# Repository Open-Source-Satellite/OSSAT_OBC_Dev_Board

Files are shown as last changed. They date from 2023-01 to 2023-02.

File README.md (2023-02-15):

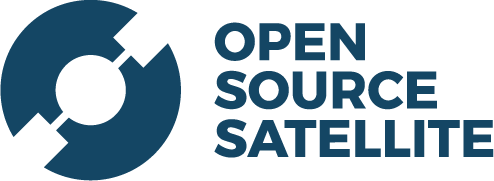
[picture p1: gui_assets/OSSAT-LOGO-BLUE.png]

# Open Source Satellite Development On Board Computer

## Contents
- [Background](#background)
- [Introduction to the OBC Development Board](#Introduction-to-the-OBC-Development-Board)
- [OBC Development Board Manual](#OBC-Development-Board-Manual)
- [Running the OSSAT OBC Application](#running-the-ossat-obc-application)

## Background
The key drivers for the Open Source Satellite (OSSAT) are to improve the affordability, accessibility and
sustainability of space; to address the market need for an improvement in the
price:performance point of small satellites; to stimulate the next wave of disruption
in the small satellite industry; and to enable the development of new missions,
applications and services.
<p style="text-align: center;">
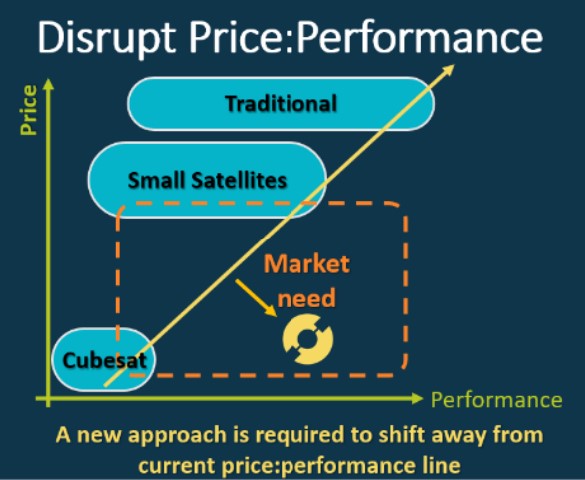
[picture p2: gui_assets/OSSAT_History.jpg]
OSSAT History

</p>
Small satellites initiated the initial market
disruption by leveraging COTS parts and
processes, but it appears that the unit cost
per spacecraft cannot be reduced much
further.  
CubeSats have been critical in recent years for
lowering the barriers to entry, however they
appear to be unable to provide sufficient
robustness and mission enabling capability to
support more demanding missions.  
The goal is to develop OSSAT to fill this gap and deliver microsatellite-class
performance for a CubeSat price, even when manufacturing in low volumes. The
aim is to increase the level of integration and robustness over subsequent missions
in order to develop a single platform that is affordable for use in vLEO (very Low
Earth Orbit), LEO (Low Earth Orbit), GEO (Geosynchronous Equatorial Orbit), Lunar and
interplanetary missions.  
OSSAT will be a performant and flexible
system that KISPE Space will be able to use to implement some of its own
commercial missions; however, simply using it for KISPE Space missions will not
result in the desired increase in accessibility to the design, nor stimulate the
market.  
Making the OSSAT design open source will maximise access and achieve the wider aims of the
Programme.  

## Introduction to the OBC Development Board
### Overview
The OSSAT OBC Development board provides a convenient hardware platform that collaborators can use, to develop satellite firmware.
The board is based upon the STM32 microcontroller and includes various interfaces for connection to other satellite sub-systems. 
The board includes an STLink programmer/debugger interface to facilitate firmware development and debugging activities.
The design shares several attributes with a sister board that is being developed for a space application.
Figure 1 shows a view of the board.

   
Figure 1:  View of the Board
<br/>
<br/>
### Features
- STM32 Microcontroller (STM32H753ZIT)
- SRAM 4Mx16bit (8Mx8bit) CMOS Static RAM
- STLink Programming and Debug interface (with UART)
- 2x CAN Bus channels (with local 120R termination), with D-Sub (9 way sockets)
- 2x UART interface
- 8x Thermistor interface (10K Negative Temperature Coefficient)
- 31x General purpose I/O lines
- Local 3V3 regulator, operating from USB supply, via Micro-USB connector
- MCU Reset Button
- 2x push-buttons for test use
- 3x status LEDs for test use
- 2x power status LEDs
- Real-time clock

### Technical Details
#### Board Overview
Figure 2 below shows a view of the fully assembled board. There are no components on the reverse side.

   
Figure 2:  View of Assembled Board
<br/>   
<br/> 
The block diagram for the Schematic is shown in Figure 3.

   
Figure 3:  Schematic Block Diagram
<br/>   
<br/> 
#### STM32 Microcontroller (STM32H753ZIT)
The STM32 MCU includes a broad set of internal features, some of which are highlighted below:
- 32-bit Arm®-M7 core
- 2Mbyte onboard Flash
- 1Mbyte RAM
- Flexible Memory controller
- Power management
- Watchdog
- Multiple communication peripherals, including CAN, I2C, SPI, UART
- ADC
- Timers and RTC
- Large number of I/O ports
- STLink / JTAG compatibility

Full details of the MCU are available from the manufacturers data sheet and reference manual, available from the STM web site. Refer to:
- DS12117: STM32H753xl Datasheet (32-bit Arm® Cortex®-M7 480MHz MCUs, 2MB Flash, 1MB RAM, 46 com. and analogue interfaces, crypto)
- RM0433: Reference manual, STM32H742, STM32H743/753 and STM32H750 Value line advanced Arm®-based 32-bit MCUs

### Related Documents
A list of documents related to this board is provided in the Manual and is listed here. This includes diagrams, design source files, manufacturing and & test information and test firmware.
- [KS-SCH-01466 (.PDF)](https://github.com/Open-Source-Satellite/OSSAT_OBC_Dev_Board/blob/main/OSSAT%20OBC%20Dev%20Board%20Drawings/KS-SCH-01466-01%20OSSAT%20OBC%20Dev%20Board%20Schematic.p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) OSSAT OBC Development Board Schematic (Schematic diagram)
- [KS-SCH-01466 (.sch)](https://github.com/Open-Source-Satellite/OSSAT_OBC_Dev_Board/blob/main/OSSAT%20OBC%20Dev%20Board%20Drawings/CAD%20Source%20Files/KS-SCH-01466-01%20OSSAT%20OBC%20Dev%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) OSSAT OBC Development Board Schematic (Fusion 360 schematic source file, in ‘Eagle’ format)
- [KS-SCH-01466 (.lbr)](https://github.com/Open-Source-Satellite/OSSAT_OBC_Dev_Board/blob/main/OSSAT%20OBC%20Dev%20Board%20Drawings/CAD%20Source%20Files/KS-SCH-01466-01%20OSSAT_OBC_Dev_Boar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) OSSAT OBC Dev board library (Fusion 360 Library file in ‘Eagle’ format, for parts used in the design)
- [KS-SCH-01466 (.xlsx)](https://github.com/Open-Source-Satellite/OSSAT_OBC_Dev_Board/blob/main/OSSAT%20OBC%20Dev%20Board%20Drawings/KS-SCH-01466-01%20OSSAT%20OBC%20Dev%20Brd%20BOM%20with%20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) OSSAT OBC Dev Board BOM with manufacturer data (Bill of materials for the board assembly)
- [KS-BRD-01467 (.brd)](https://github.com/Open-Source-Satellite/OSSAT_OBC_Dev_Board/blob/main/OSSAT%20OBC%20Dev%20Board%20Drawings/CAD%20Source%20Files/KS-SCH-01467%20OSSAT%20OBC%20Dev%20B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) OSSAT OBC Development Board PCB (Fusion 360 PCB source file in ‘Eagle’ format)
- [KS-BRD-01467 (.zip)](https://github.com/Open-Source-Satellite/OSSAT_OBC_Dev_Board/blob/main/OSSAT%20OBC%20Dev%20Board%20Drawings/Gerber%20Files/KS-BRD-01467-02%20OSSAT%20Sw%20Dev%20Board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) OSSAT OBC Dev Board PCB Manufacturing files	(Gerber file set and PnP file)
- [KS-BRD-01467 (.docx)](https://github.com/Open-Source-Satellite/OSSAT_OBC_Dev_Board/blob/main/OSSAT%20OBC%20Dev%20Board%20Drawings/KS-BRD-01467-02%20OSSAT%20OBC%20Dev%20board%20PCB%20Layer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) OSSAT OBC Dev Board Layer Stack-up (Defines the layer stack and pcb materials / thicknesses for the board)
- [KS-DOC-01526 (.docx)](https://github.com/Open-Source-Satellite/OSSAT_OBC_Dev_Board/blob/main/OSSAT%20OBC%20Dev%20Board%20Drawings/KS-DOC-01526-02%20OSSAT%20OBC%20Dev%20Board%20Verificatio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) OSSAT OBC Dev Board Verification Procedure	(Used to confirm board function after build)
- [KS-DOC-01529 (.docx)](https://github.com/Open-Source-Satellite/OSSAT_OBC_Dev_Board/blob/main/OSSAT%20OBC%20Dev%20Board%20Drawings/KS-DOC-01529-01%20OSSAT%20OBC%20Dev%20Board%20Build%20Doc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) OSSAT OBC Dev Board Build Document (Build process control document)
- [KS-SOF-01541 (software)](https://github.com/Open-Source-Satellite/OSSAT_OBC_Dev_Board/releases/tag/KS-SOF-01541-01) Software to support h/w test of the OSSAT OBC dev board	(Test Software)

## OBC Development Board Manual
Document [KS-DOC-01543 is the manual](https://github.com/Open-Source-Satellite/OSSAT_OBC_Dev_Board/blob/main/KS-DOC%2001543-01%20OSSAT%20OBC%20Dev%20Board%20Manual.docx) for the board. It covers:
- Board features
- Technical details
- Building the board
- Testing the board
- Using the board

## Running the OSSAT OBC Application
Within one year of the first launch of the OSSAT, the OSSAT OBC Application software will become open source. In the interim time, in order to develop/build and run the OSSAT OBC Application, you'll need to become an OSSAT collaborator ([Click Here](https://www.opensourcesatellite.org/register/)).
If you are an OSSAT collaborator, that's great... Click [here](/OBC_CODE_README.md) to find out how to run the OSSAT OBC Application on this development board.

## Licenses
All information in this repository is licensed Open Source through the Creative Commons license:

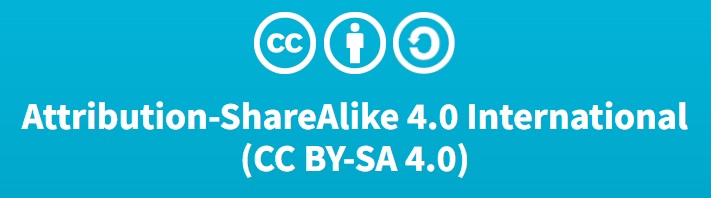
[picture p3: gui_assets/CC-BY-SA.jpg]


## Get Involved
If you wish to contribute directly to the development of OSSAT, have a look at the existing Github issues and register [here](https://www.opensourcesatellite.org/register/).

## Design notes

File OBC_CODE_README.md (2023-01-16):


# Running application code on the OBC
This readme gives the details you'll need to run our OSSAT application on our OSSAT OBC development board, it also gives details of how to use the simple command line interface and how to get the file system going.  

## Contents
- [Building the code](#building-the-code)
- [Running the code](#running-the-code)
- [Using the CLI](#using-the-cli)
- [Formatting the disk](#formatting-the-disk)
- [Downloading files](#deownloading-files)
- [Uploading files](#uploading-files)
- [Reading the Command and Error Log](#reading-the-command-and-error-log)

## Building the code
If you are an OSSAT collaborator, you'll be able to access the OBC application code at [this](https://github.com/Open-Source-Satellite/OSS-Demo-Project-STM32H7) repository. For information about building the code, go to this repository.

**NOTE: The STMCubeIDE project includes build configurations for different builds (e.g. Unit Tests, Bootloader, Main Application etc). Therefore, before hitting the build button, you'll need to switch to the relevant build configuration which is MAIN_IMAGE_DEBUG_SECTOR_0_KS_OBC. This change can be made by navigating to the Project dropdown->Build Configurations->Set Active->MAIN_IMAGE_DEBUG_SECTOR_0_KS_OBC. See the below image:**

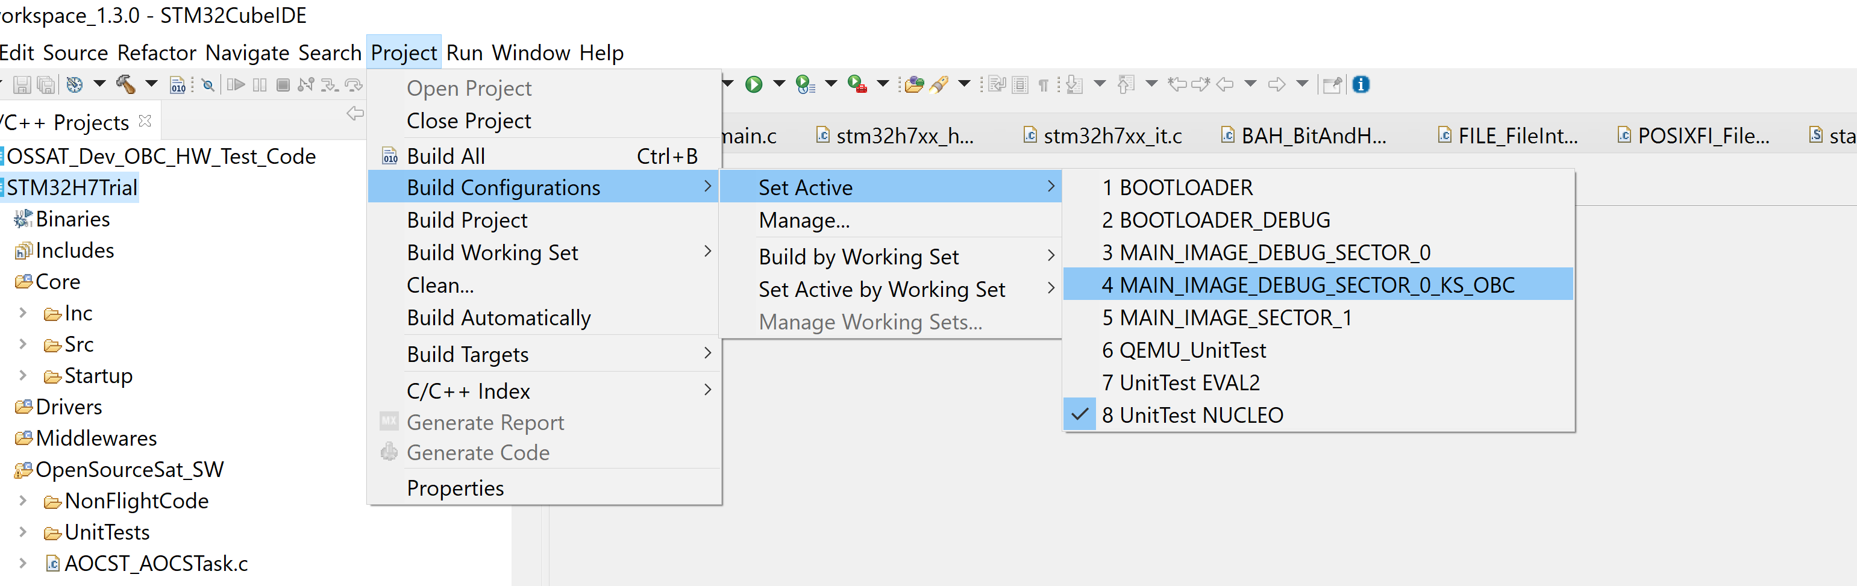
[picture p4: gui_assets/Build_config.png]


## Running the code
In order to run the code, you'll need some form of UART/Serial terminal program. We tend to use [TeraTerm](https://ttssh2.osdn.jp/index.html.en). You'll also need an [ST Link SWD/JTAG device](https://www.st.com/en/development-tools/stlink-v3set.html). The board is designed with a compatible SWD/JTAG connector.

Perform the following procedure:
1. Connect the ST Link to the board at one end and to your PC running STM Cube on the other end.



2. Apply 5V to the micro USB power connection to the board (a seperate connector to the ST-Link). (setting any relevant current limit to 0.5A should provide plenty of power to overcome in-rush).
3. Run your chosen terminal program at 115200 baud 8-N-1 configuration. Select the COM port labelled "STMicroelectronics STLink Virtual COM Port"

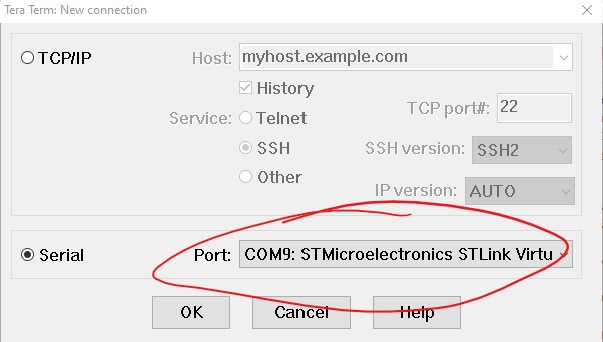
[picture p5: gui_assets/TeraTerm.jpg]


4. Once the code is built, you can either load and run (the green "go" icon) OR load, and debug run (the bug symbol) 



5. You should now observe some output on the Command Line Interface (CLI) through your chosen serial program.

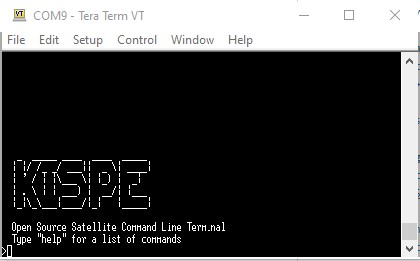
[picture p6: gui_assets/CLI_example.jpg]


6. Typing "help" into the CLI will list the available commands.

## Formatting the disk
Since the OSSAT development board does not include non-volatile memory (unlike the flight version that makes use of MRAM), you'll need to format the disk following any power cycle. The board features 8 MBytes of SRAM that can be formatted using the CLI command "fdisk OSS:/"
You may notice some error messages in response to the disk formatting that relate to the closure of files that may not exist.

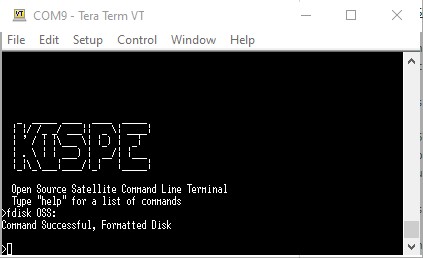
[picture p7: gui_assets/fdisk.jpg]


Once formatted... Another reset (via the MCU reset button) will cause the command and error log file to be created.

## Downloading files
You'll find that you can navigate around the file system through the Linux-esque commands such as "ls", "cd", "pwd". You can also use the download command to download files, the command gives you 10 seconds (to start file logging in your chosen serial program) before printing the content of the file to the serial terminal.

## Uploading files
At the time of writing, the CLI code uses inefficient STDIO function calls to read the serial data. These calls are too slow to keep up with serial data at the maximum rate. Therefore, we've written a small Windows Powershell utility that slows down the data transmission to a level that the STDIO calls can support. Therefore, in order to upload files, run the following steps:

1. Install PowerShell v7+ for Windows.
2. navigate to the "Scripts" subdirectory in the STM32Cube Project.
3. Disconnect any serial programs from the serial port
4. run the "file_uploader.ps1" script
```bash
./file_uploader 
```

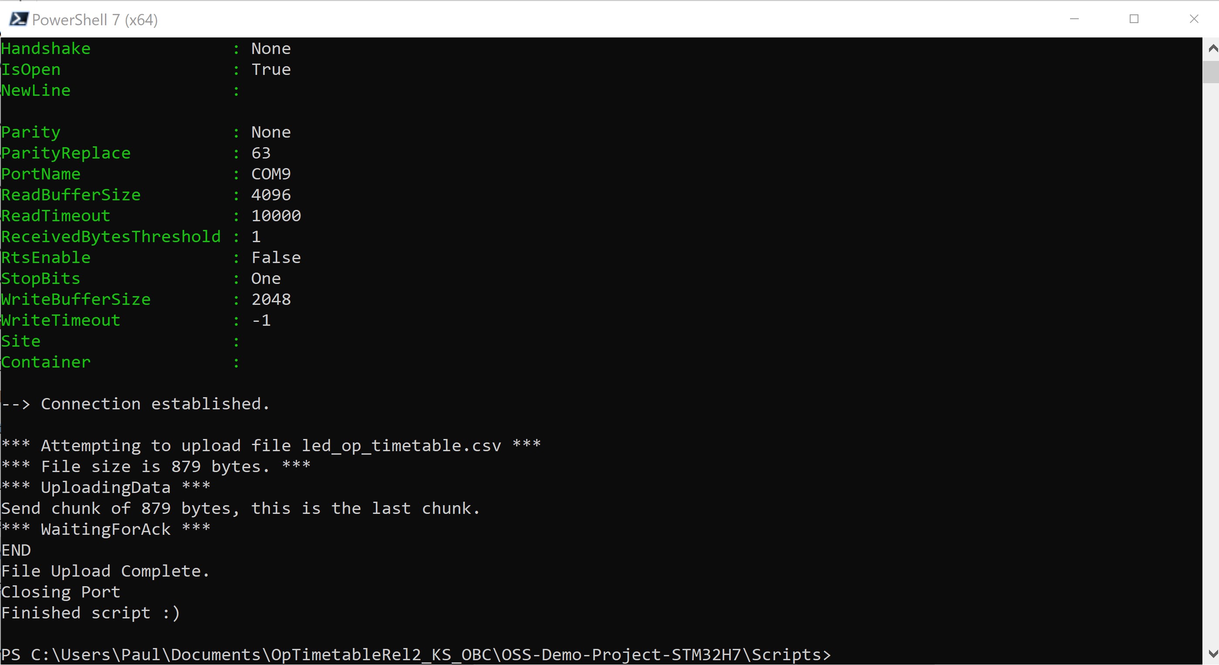
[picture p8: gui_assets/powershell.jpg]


**NOTE: there are other powershell command line options available that can e.g. change baud rate, change destination path/name etc etc. Open the script to observe the full list.**

## Reading the Command and Error Log
The OBC software includes a command and error log that records lot of the activities performed on board. To see this history, naviagate to the OSS:/CmdAndErrLogs directory and download the latest file.

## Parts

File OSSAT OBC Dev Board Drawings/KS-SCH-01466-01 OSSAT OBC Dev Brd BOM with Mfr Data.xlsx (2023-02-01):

KS-SCH-01466-01 OSSAT OBC Dev Board Bill of Materials
To be used with shematic KS-SCH-01466-01 Schematic and KS-SCH-01466-02 PCB artwork
Item no | Qty | Refs | Description | Manufacturer | Manf Part number | Vendor | Stock No
1 | 1 | C58 | 100pF MLCC 0805 COG 50V 5% | Kemet | C0805C101J5GACTU | Farnell | 1414656
2 | 2 | C35, C36 | 10pF MLCC 0805 COG 50V 5% Q200 | Kemet | C0805C100J5GACAUTO | Farnell | 2070433
3 | 0 | C16, C17 | #N/A | #N/A | #N/A | #N/A | #N/A
4 | 24 | C1, C6, C7, C8, C9, C10, C11, C12, C13, C14, C15, C18, C19, C20, C25, C26, C28, C31, C34, C37, C38, C39, C48, C63 | 100nF MLCC 0805 X7R 50V 10% | Kemet | C0805C104K5RACTU | Farnell | 1414664
5 | 2 | C24, C49 | 47nF MLCC 0805 X7R 50V 10% Q200 | Kemet | C0805C473K5RACAUTO | Farnell | 2070486
6 | 12 | C27, C29, C30, C32, C40, C41, C42, C43, C44, C45, C46, C47 | 1uF MLCC 0805 X7R 25V 10% | Kemet | C0805C105K3RECTU | Farnell | 2991344
7 | 1 | C5 | 4u7 MLCC 0805 X7R 16V 10% | Kemet | C0805C475K4RACTU | Farnell | 2118133
8 | 2 | C3, C4 | 2u2 MLCC 0805 X7R 16V 10% Q200 | Kemet | C0805C225K4RECAUTO | Farnell | 2991362
9 | 1 | C64 | 10uF MLCC 1210 X7R 25V 10% Q200 | Kemet | C1210C106K3RACAUTO | Farnell | 2070524
10 | 4 | C2, C21, C22, C23 | 47uF MLCC 1210 X7R 10V 10% | Murata | GRM32ER71A476KE15L | Farnell | 1797018
11 | 1 | C57 | 470uF ELECTROLYTIC 16V 20% PTH 10Dx12.5Hx5P Rubycon YXF | Rubycon | 16YXF470MEFC10X12.5 | Farnell | 1144616
12 | 2 | J3, J4 | 52F 2 Row Skt-Strip 2.54P Samtec ESQ-nnn-12-G-D | Samtec | ESQ-126-12-G-D | Farnell | 2856394
13 | 1 | J1 | 14M 2 Row Micro Header 1.27p Samtec FTSH-1nn-01-F-D-K | Samtec | FTSH-107-01-F-D-K | Mouser | 200-FTSH10701FDK
14 | 2 | J7, J8 | 9F D-Sub Vert Scw-Post Amphenol FCI DELTA-D | Amphenol FCI | LD09S24A4GV00LF | Farnell | 3367583
15 | 1 | J6 | Micro-USB 90deg Amphenol 10103594-0001LF | Amphenol | 10103594-0001LF | Farnell | 2293752
16 | 0 | TP1, TP2, TP3, TP4, TP5, TP6, TP7, TP8, TP9, TP10, TP11, TP12, TP13, TP14, TP15, TP16, TP17 | #N/A | #N/A | #N/A | #N/A | #N/A
17 | 5 | D2, D3, D9, D10, D11 | BAT54S Dual Schottky SOT23 diodes in series | NXP | BAT54S,215 | Farnell | 1081194
18 | 1 | U4 | 74LVC138AD 3-8 decoder SOIC16 Max 125C | NXP | 74LVC138AD,118 | Farnell | 2463808
19 | 2 | U12, U15 | IS61WV204816BLL-10TLI SRAM 4MByte (2Mx16) 48pin-TSOP Max 85C | ISSI | IS61WV204816BLL-10TLI | Mouser | 870-WV204816BLL10TLI
20 | 1 | U2 | STM32H753ZIT6 MCU 144pin Max 85C | STM | STM32H753ZIT6 | Farnell | 2851002
21 | 1 | U13 | 3V3 LFnnABV LDO Regulator TO-220 Max 125C | STM | LF33ABV | Farnell | 1087184
22 | 2 | U10, U11 | MAX33054EASA+ CAN-Tranceiver SOIC8 Max 125C | Maxim | MAX33054EASA+ | Farnell | 2915380
23 | 2 | FB1, FB2 | 600R Bead 0805 600R at 100MHz WE-CBF-SMD | Wurth | 742792040 (WE-CBF-SMD) | Farnell | 1635735
24 | 0 | H1, H2, H3, H4, H5, H6 | #N/A | #N/A | #N/A | #N/A | #N/A
25 | 5 | LED1, LED2, LED3, LED4, LED5 | LED Yellow 0805 120deg 590nm 150mcd | Kingbright | APT2012SYCK | Mouser | 604-APT2012SYCK
26 | 1 | X1 | Xtal 32.768KHz 12p5 Max 125c Size 3.2x1.5x0.8 | NDK | NX3215SA-32.768K-STD-MUS-2 | Mouser | 344-NX3215SA32768K2
27 | 1 | X2 | Xtal 25MHz 10pF Max 125c Size 2.0x1.6x0.45 | Abracon | ABM11AIG-25.000MHZ-4Z-T3 | Farnell | 3819707
28 | 5 | R4, R8, R9, R25, R28 | 0R RES 0805 LINK 2A | NIC COMPONENTS | NRC10ZOTRF | Farnell | 3223535
29 | 5 | R15, R16, R19, R20, R37 | 100R RES 0805 0.125W 1% AEC-Q200 | Vishay | CRCW0805100RFKEA | Farnell | 1469862
30 | 3 | R83, R84, R85 | 10K RES 0805 0.125W 1% AEC-Q200 | Vishay | CRCW080510K0FHEAP | Farnell | 3546411
31 | 1 | R86 | 1K RES 0805 0.125W 1% AEC-Q200 | Vishay | CRCW08051K00FKEA | Mouser | 71-CRCW0805-1.0K-E3
32 | 1 | R43 | 200R RES 0805 0.125W 1% AEC-Q200 | Vishay | CRCW0805200RFKEA | Farnell | 1469895
33 | 1 | R38 | 2K RES 0805 0.125W 1% AEC-Q200 | Vishay | CRCW08052K00FKEA | Mouser | 71-CRCW0805-2.0K-E3
34 | 4 | R65, R78, R81, R89 | 33R RES 0805 0.125W 1% AEC-Q200 | Panasonic | ERJP06F33R0V | Farnell | 1750735
35 | 7 | R13, R17, R35, R36, R63, R79, R82 | 47K RES 0805 0.125W 1% AEC-Q200 | Vishay | CRCW080547K0FKEB | Farnell | 3546437
36 | 3 | R5, R6, R14 | 4K7 RES 0805 0.125W 1% AEC-Q200 | Vishay | CRCW08054K70FKEA | Farnell | 1469923
37 | 4 | R26, R27, R29, R30 | 60R4 RES 0805 0.125W 1% AEC-Q200 | Panasonic | ERJ6ENF60R4V | Farnell | 2303416
38 | 1 | R87 | 68R RES 0805 0.125W 1% AEC-Q200 | Vishay | RCS080568R0FKEA | Farnell | 3235183
39 | 4 | R21, R22, R23, R24 | 910R RES 0805 0.125W 1% AEC-Q200 | Vishay | CRCW0805910RFKEA | Mouser | 71-CRCW0805910RFKEA
40 | 0 | R39, R40, R41, R42, R44, R45, R46, R88 | #N/A | #N/A | #N/A | #N/A | #N/A
41 | 4 | R1, R2, R11, R12 | 10K RES 4-isolated 1206 1% Q200 | Bourns | CAY16A-1001F4LF | Farnell | 3754800
42 | 2 | R3, R10 | 1K RES 4-isolated 1206 1% Q200 | Bourns | CAY16A-1001F4LF | Farnell | 3754799
43 | 3 | S1, S2, S3 | 1PST SMD Momentary push-button 12V 50mA | Sparkfun | COM-08720 | Mouser | 474-COM-08720
44 | 1 | D4 | 3V3 TVS CDSOD323-Tnn 350W Unidirectional | Bourns | CDSOD323-T03 | Farnell | 2341910
45 | 1 | D1 | 5V0 TVS CDSOD323-Tnn 350W Unidirectional | Bourns | CDSOD323-T05 | Farnell | 2341914

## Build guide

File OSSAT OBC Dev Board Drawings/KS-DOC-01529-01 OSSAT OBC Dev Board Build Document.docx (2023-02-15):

KS-BRD01529-01: OSSAT OBC Dev board build document

This document defines the prototype build process for this PCB assembly. It covers the process from: purchasing, through assembly and test. The reference for this document is in the footer.

General Informaiton

General
This document (reference) | KS-DOC-01529-01 (also referenced in the footer)
Applicability | Applies to the OSSAT OBC
Top level part number | KS1-BRD-01467
Date
Produced By
Quantity to build
Serial number(s)
Solder Type(s)

Workflow

# | Action | Info | Notes | Complete

1 | Prints and documents | .
| Schematic | KS-SCH-01466-01 pdf
| BOM PCB | KS-SCH-01466-01 xlxs KS-BRD-01467-02 (Gerber files)
| Verification Document | KS-DOC-01526-02 docx
| Firmware | KS-SOF-01541
2 | Procurement | .
| Components
| Bare Board
| Stencil
3 | Kitting & Free Issue | .
| Kitting
| Free Issue to sub-con
4 | Build | (In house build)
| Pre-Clean | Wipe with Isopropanol
| Solder paste application | Stencil application
| SMD Stuffing order | 1: MCU 2: SRAMS 3: Other ICs 4: Diodes and other semis 5: Resistors 6: Capacitors (small to large) 7: Other SMD
| SMD Soldering | In-house Reflow Oven
| PTH Stuffing & soldering | All through hole devices fitted and soldered
| Mechanical assembly | Fit self-adhesive feet
5 | Cleaning | .
| Post soldering cleaning | SMD=None. Hand soldering=Isopropanol
| Inspection | .
6 | Confirm correct build | Part of test
7 | Test | .
| Functional/proving test | In-house test

Notes

2 CC BY-SA 4.0: Open Source Satellite opensourcesatellite.org

Issue XA CAVEAT DOC REF. 09 December 2022 CAVEAT Page ii

CAVEAT CAVEAT

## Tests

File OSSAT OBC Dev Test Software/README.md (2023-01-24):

# OSSAT_OBC_hw_test
Software that tests the OBC

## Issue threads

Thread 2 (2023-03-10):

Battery back up for the SRAM

PaulMadle, 2023-03-10:
This dev board has 2*SRAM external to the processor whereas the flight board has non-volatile MRAM.
At the moment, every time you power cycle the board, the file systems gets wiped... It would be nice in the memory could be made non-volatile? Does someone fancy adding battery backup for the RAM?

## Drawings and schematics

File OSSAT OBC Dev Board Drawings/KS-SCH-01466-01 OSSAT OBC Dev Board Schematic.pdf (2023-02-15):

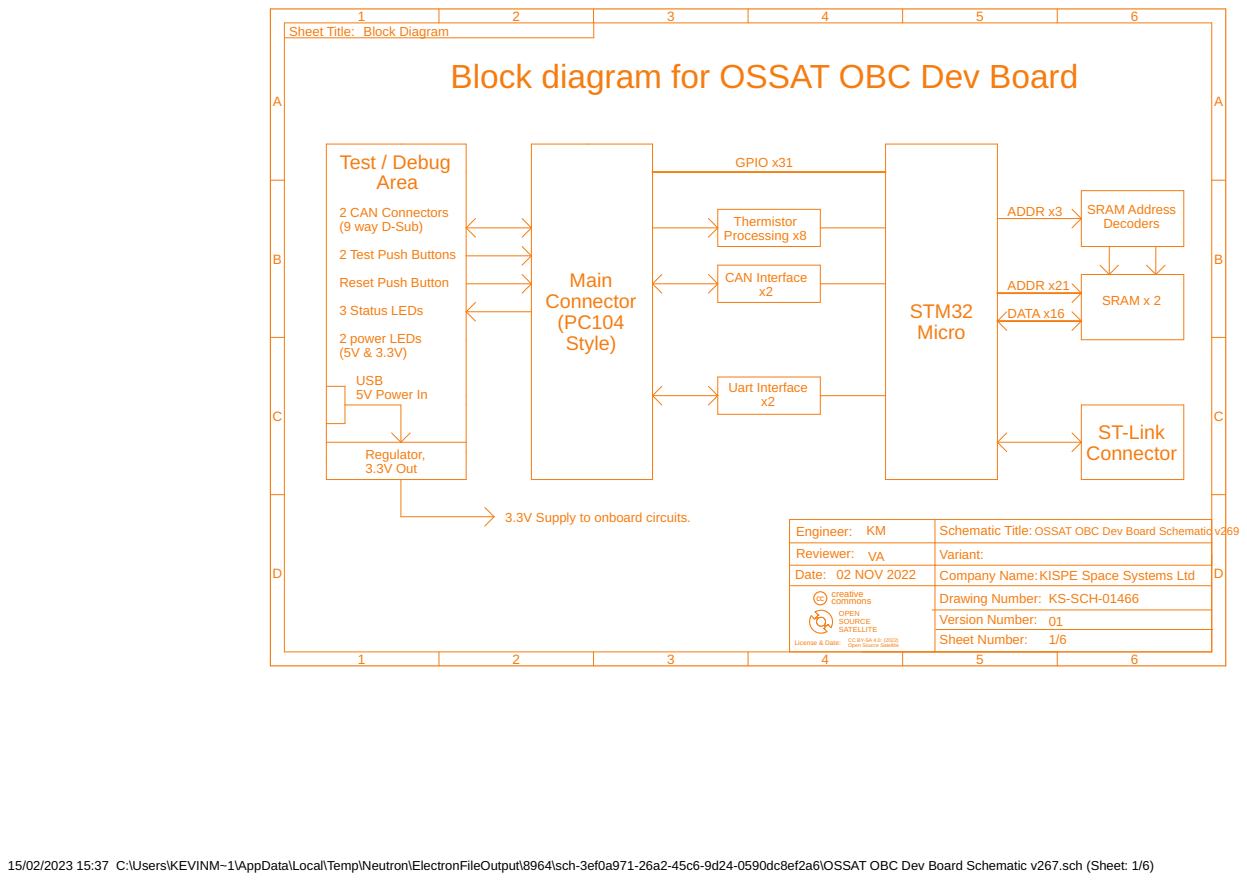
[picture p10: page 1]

Sheet Title: Block Diagram Block diagram for OSSAT OBC Dev Board

3.3V Supply to onboard circuits.

KM Engineer: | Schematic Title:

Reviewer: VA | Variant:
Date: 02 NOV 2022 | Company Name:KISPE Space Systems Ltd

15/02/2023 15:37 C:\Users\KEVINM~1\AppData\Local\Temp\Neutron\ElectronFileOutput\8964\sch-3ef0a971-26a2-45c6-9d24-0590dc8ef2a6\OSSAT OBC Dev Board Schematic v267.sch (Sheet: 1/6)

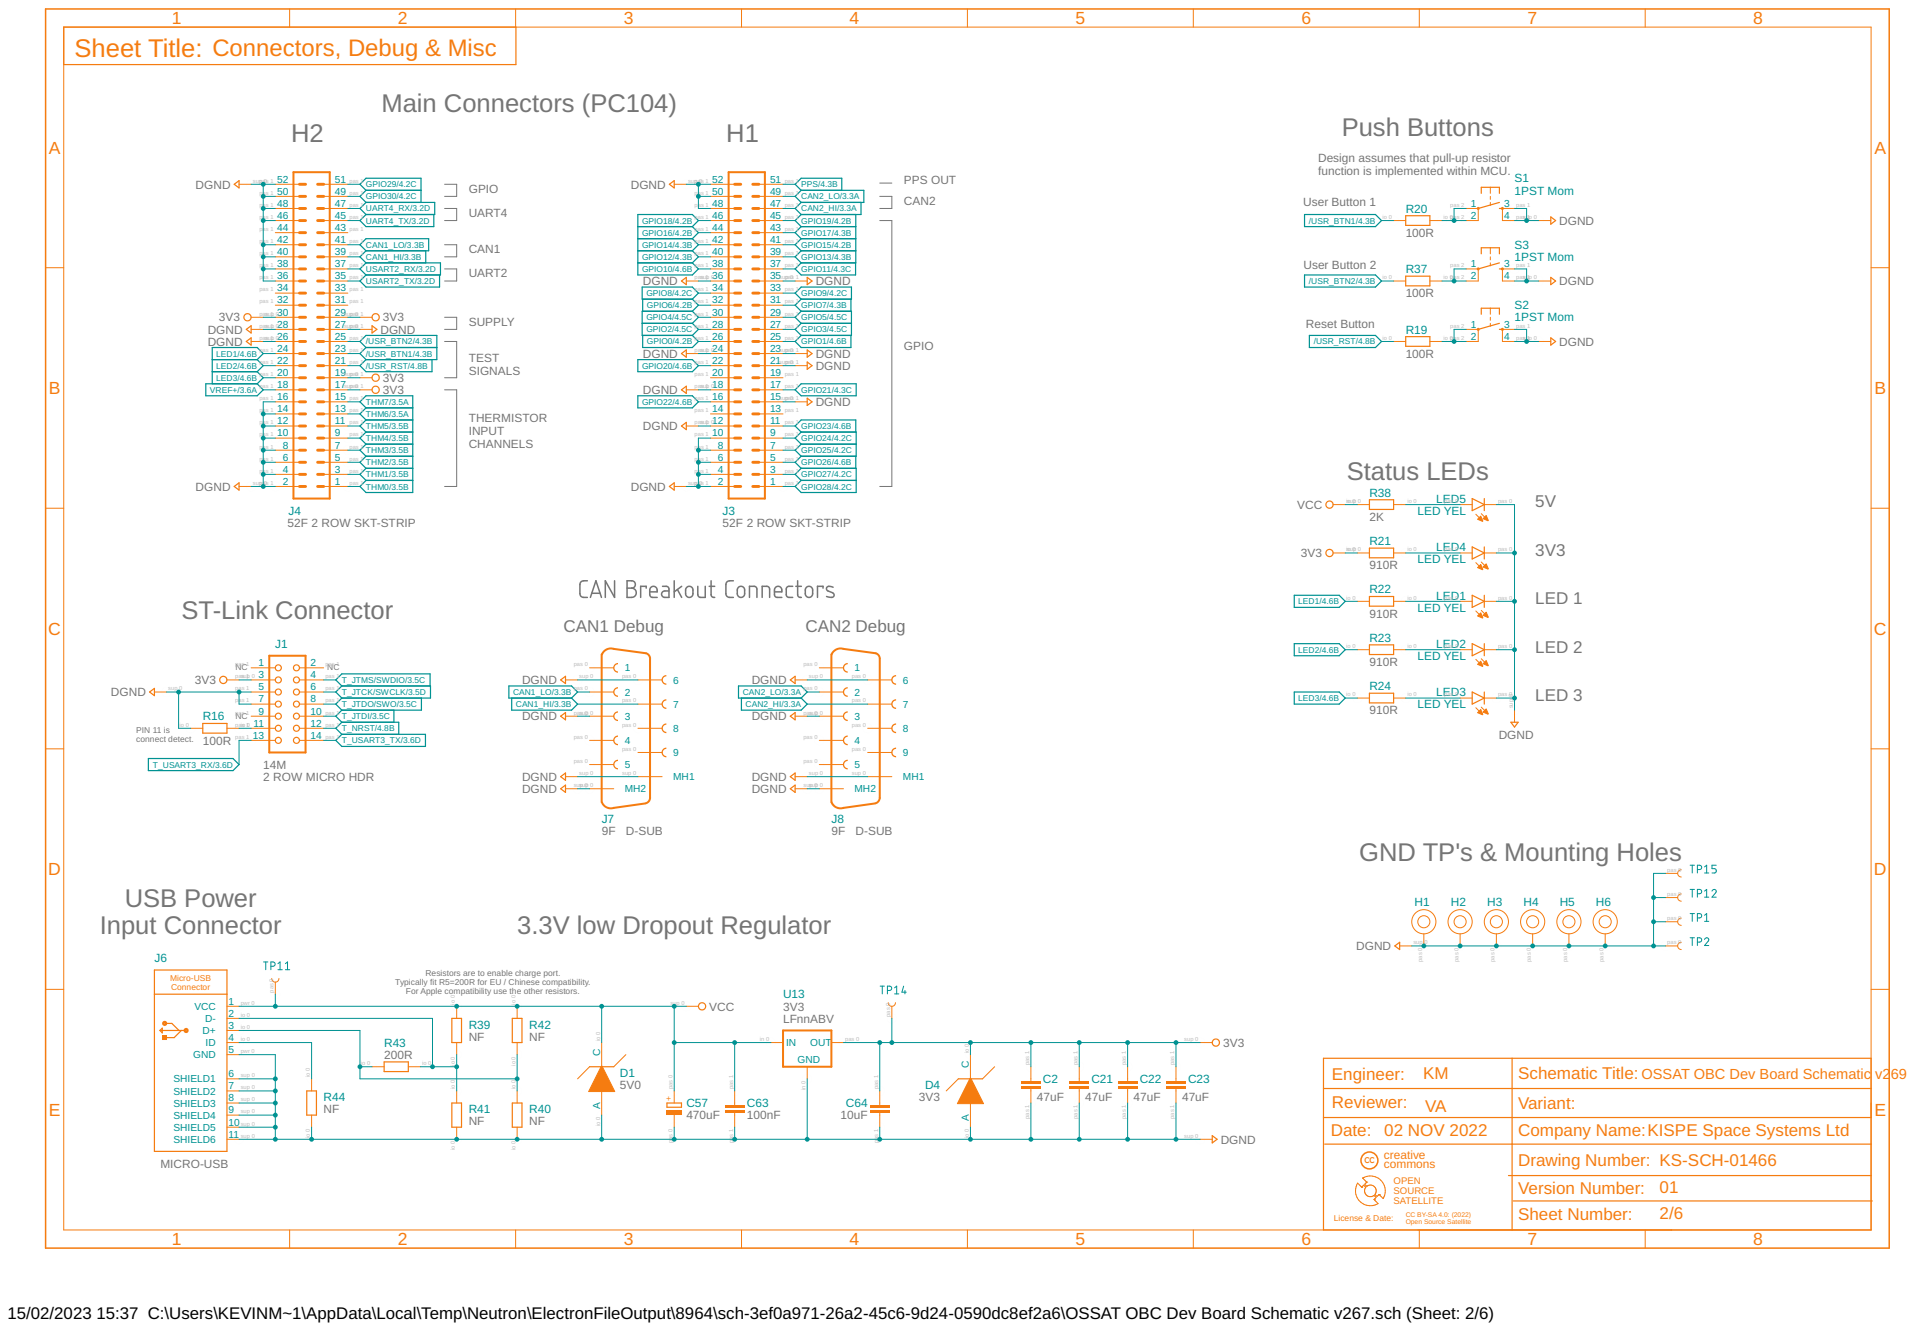
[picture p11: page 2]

Design assumes that pull-up resistor

function is implemented within MCU. UART4
GPIO

Reset Button Status LEDs

pas 1 8 | 7 pas 1
6 pas 1 | 5 pas 1
pas 1 4 | 3 pas 1
2 pas 1 | 1 pas 1

Resistors are to enable charge port. Typically fit R5=200R for EU / Chinese compatibility. For Apple compatibility use the other resistors. USB Power
Input Connector

15/02/2023 15:37 C:\Users\KEVINM~1\AppData\Local\Temp\Neutron\ElectronFileOutput\8964\sch-3ef0a971-26a2-45c6-9d24-0590dc8ef2a6\OSSAT OBC Dev Board Schematic v267.sch (Sheet: 2/6)

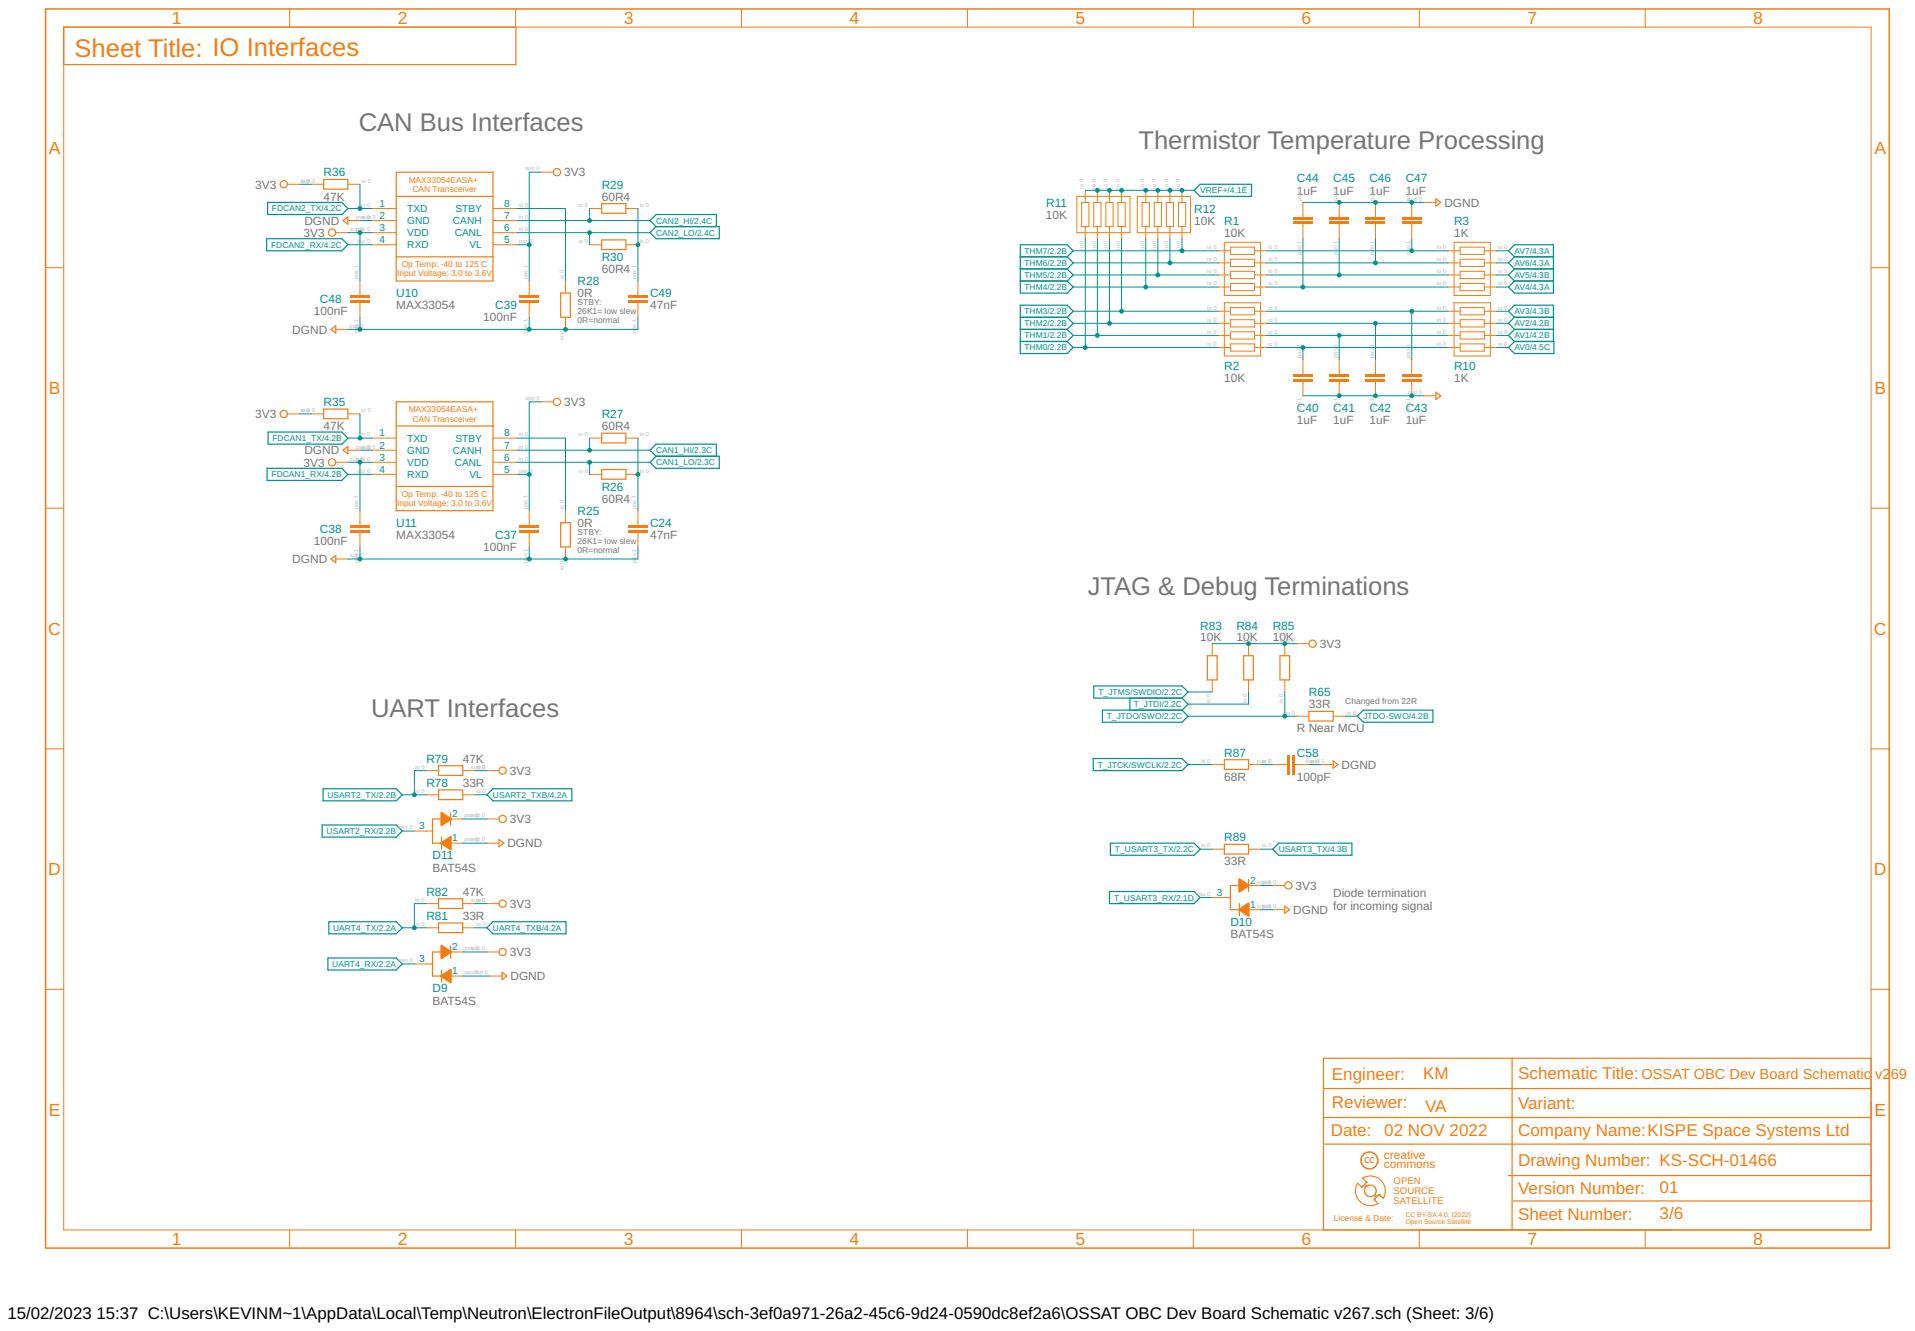
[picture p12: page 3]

MAX33054EASA+ CAN Transceiver Op Temp: -40 to 125 C

Engineer: KM | Schematic Title:

Reviewer: VA | Variant:
Date: 02 NOV 2022 | Company Name:KISPE Space Systems Ltd

15/02/2023 15:37 C:\Users\KEVINM~1\AppData\Local\Temp\Neutron\ElectronFileOutput\8964\sch-3ef0a971-26a2-45c6-9d24-0590dc8ef2a6\OSSAT OBC Dev Board Schematic v267.sch (Sheet: 3/6)

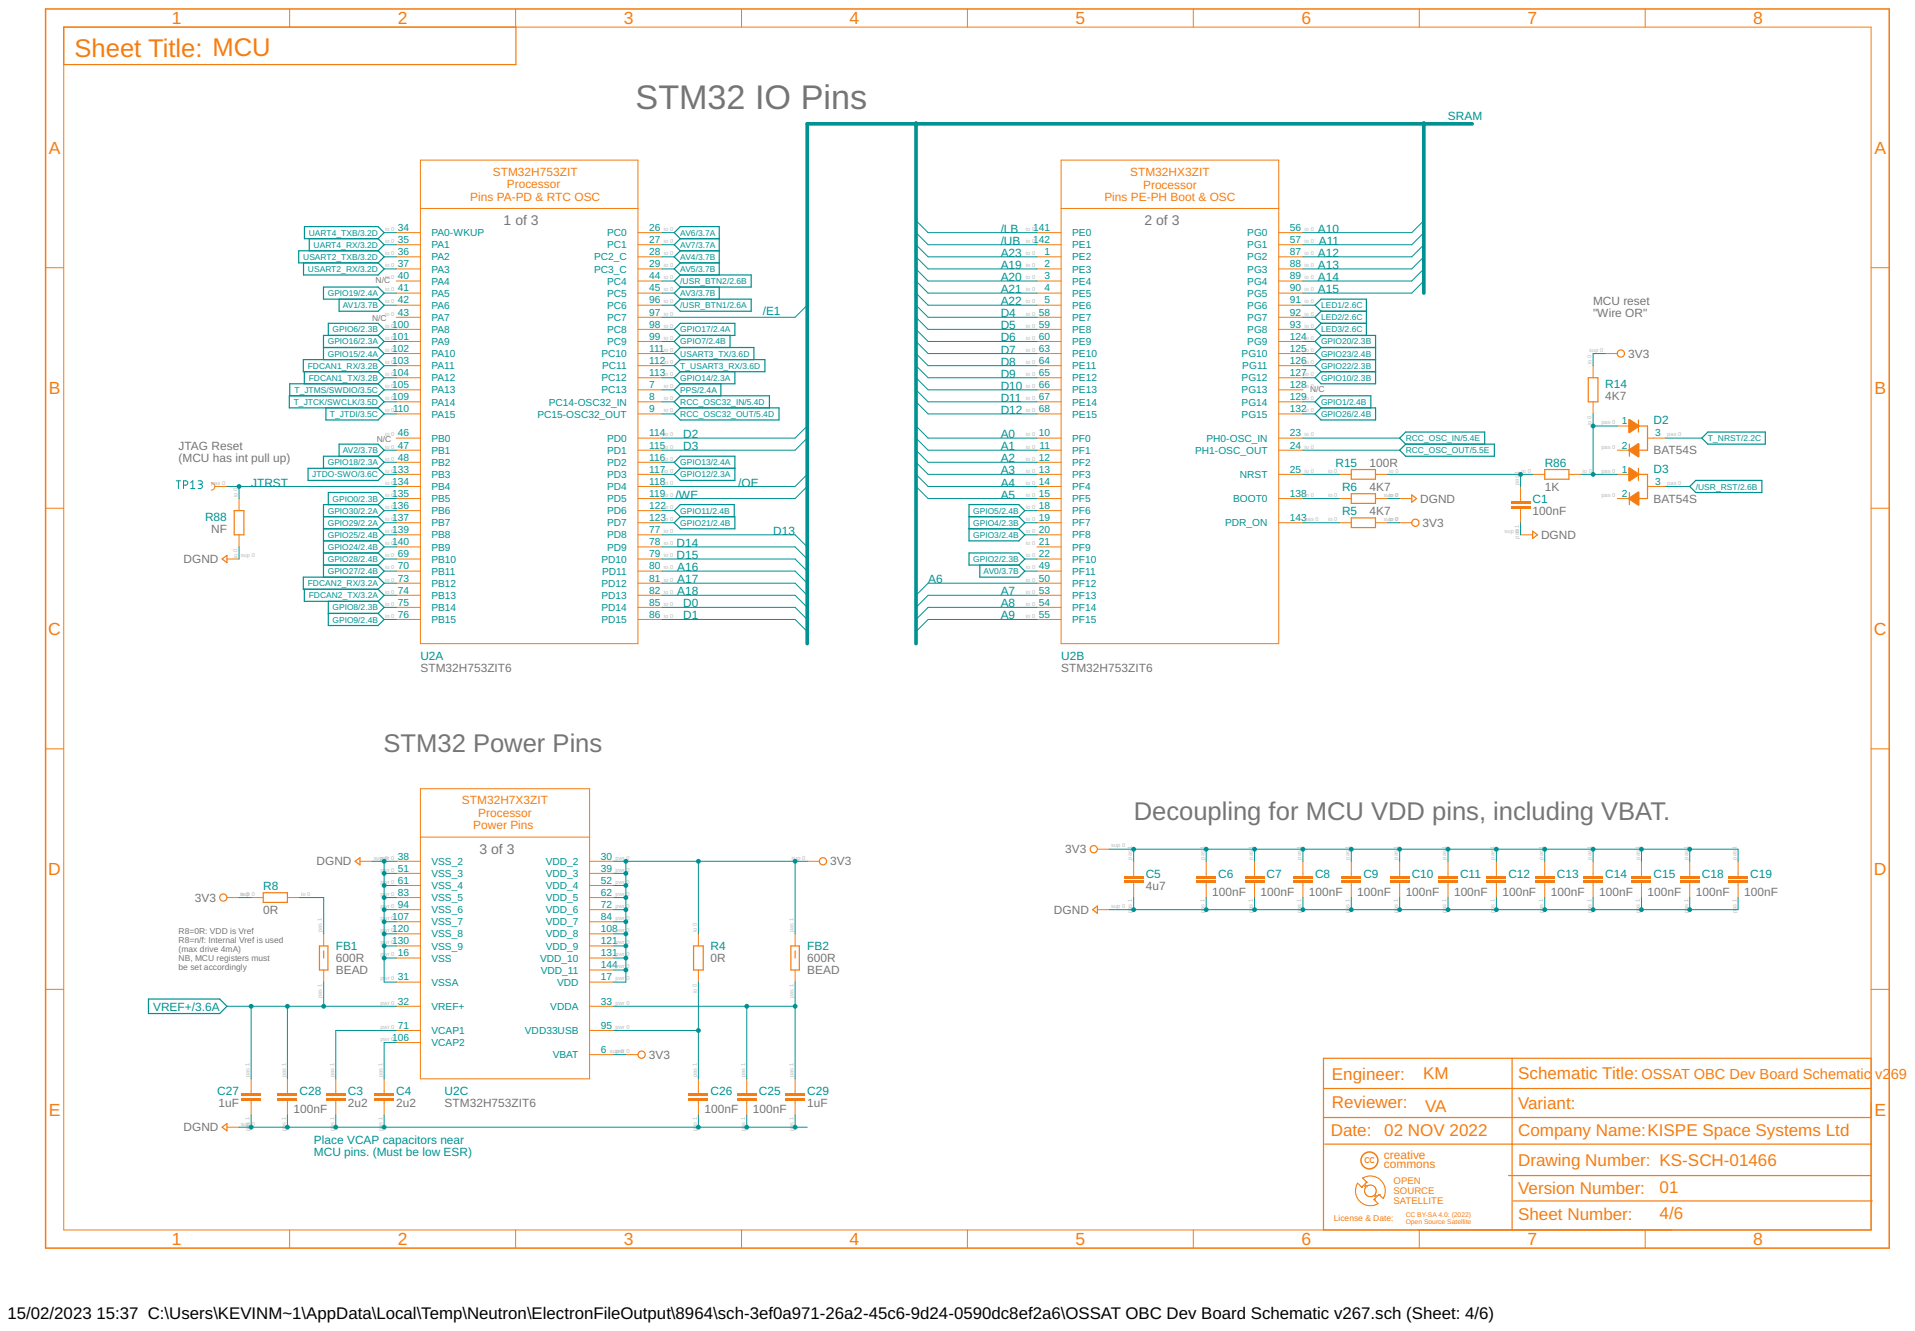
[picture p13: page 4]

STM32H753ZIT
Processor Pins PA-PD & RTC OSC

STM32HX3ZIT
Processor Pins PE-PH Boot & OSC

MCU reset "Wire OR"

JTAG Reset
(MCU has int pull up)

Decoupling for MCU VDD pins, including VBAT.

R8=0R: VDD is Vref R8=n/f: Internal Vref is used

(max drive 4mA) NB, MCU registers must be set accordingly

Engineer: KM | Schematic Title:

Reviewer: VA | Variant:
Date: 02 NOV 2022 | Company Name:KISPE Space Systems Ltd

Place VCAP capacitors near MCU pins. (Must be low ESR)

15/02/2023 15:37 C:\Users\KEVINM~1\AppData\Local\Temp\Neutron\ElectronFileOutput\8964\sch-3ef0a971-26a2-45c6-9d24-0590dc8ef2a6\OSSAT OBC Dev Board Schematic v267.sch (Sheet: 4/6)

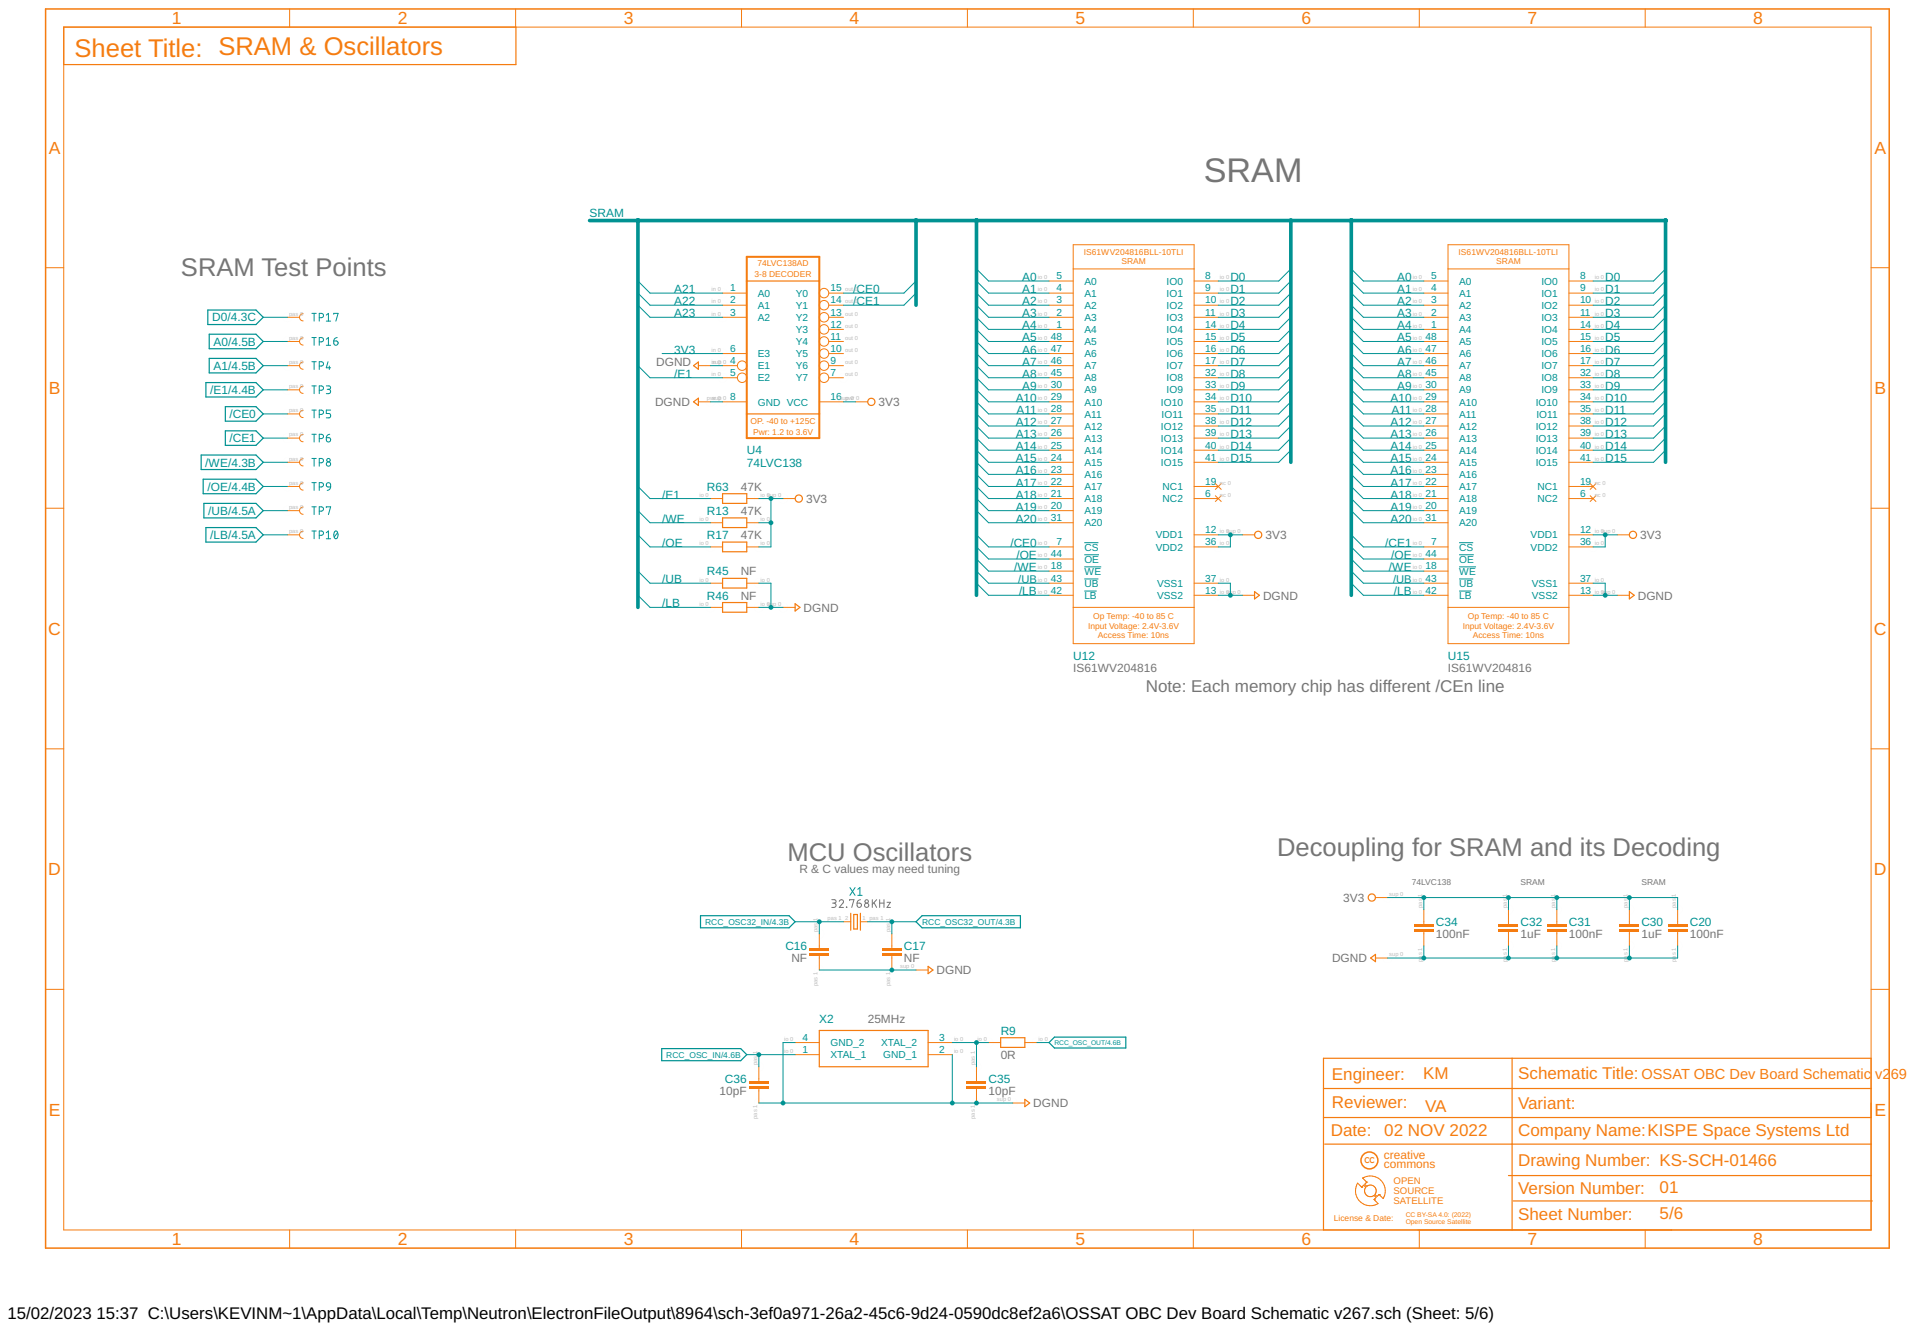
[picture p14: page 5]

Note: Each memory chip has different /CEn line

Decoupling for SRAM and its Decoding

R & C values may need tuning

Engineer: KM | Schematic Title:

Reviewer: VA | Variant:
Date: 02 NOV 2022 | Company Name:KISPE Space Systems Ltd

15/02/2023 15:37 C:\Users\KEVINM~1\AppData\Local\Temp\Neutron\ElectronFileOutput\8964\sch-3ef0a971-26a2-45c6-9d24-0590dc8ef2a6\OSSAT OBC Dev Board Schematic v267.sch (Sheet: 5/6)

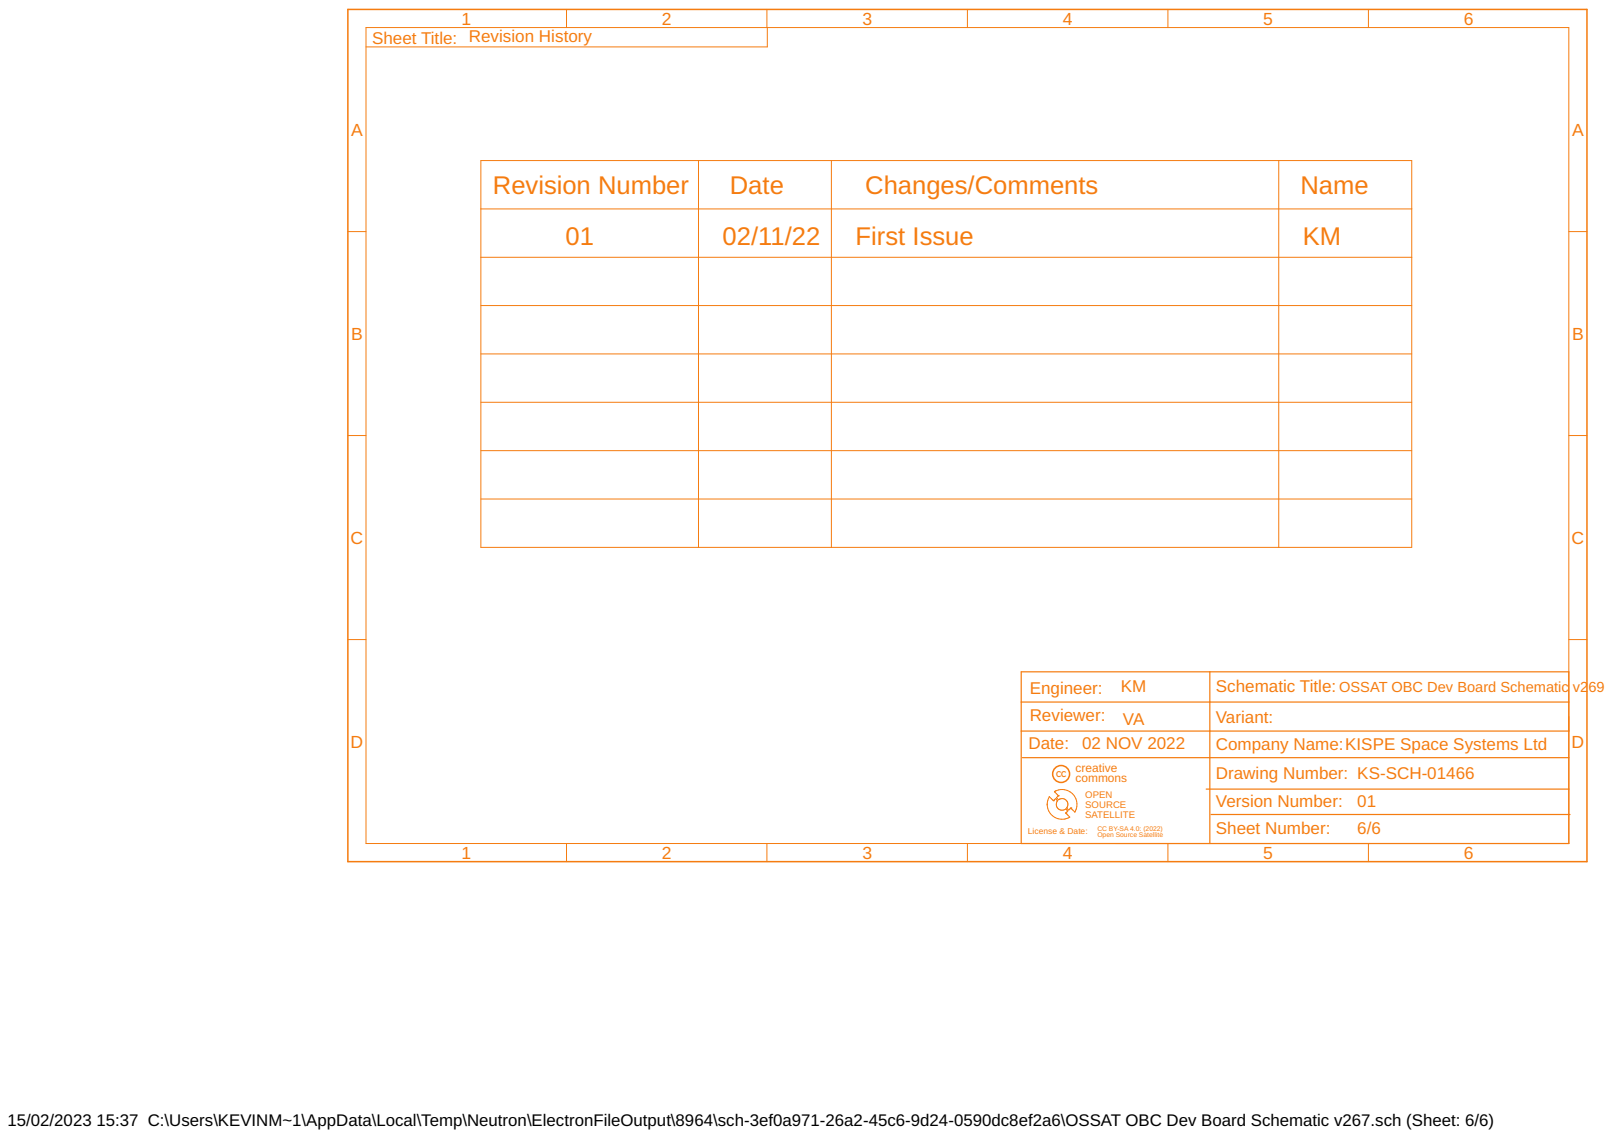
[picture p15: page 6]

Revision History Sheet Title:

Revision Number | Date | Changes/Comments | Name

01 | 02/11/22 | First Issue | KM

KM Engineer: | Schematic Title:

Reviewer: VA | Variant:
Date: 02 NOV 2022 | Company Name:KISPE Space Systems Ltd

15/02/2023 15:37 C:\Users\KEVINM~1\AppData\Local\Temp\Neutron\ElectronFileOutput\8964\sch-3ef0a971-26a2-45c6-9d24-0590dc8ef2a6\OSSAT OBC Dev Board Schematic v267.sch (Sheet: 6/6)

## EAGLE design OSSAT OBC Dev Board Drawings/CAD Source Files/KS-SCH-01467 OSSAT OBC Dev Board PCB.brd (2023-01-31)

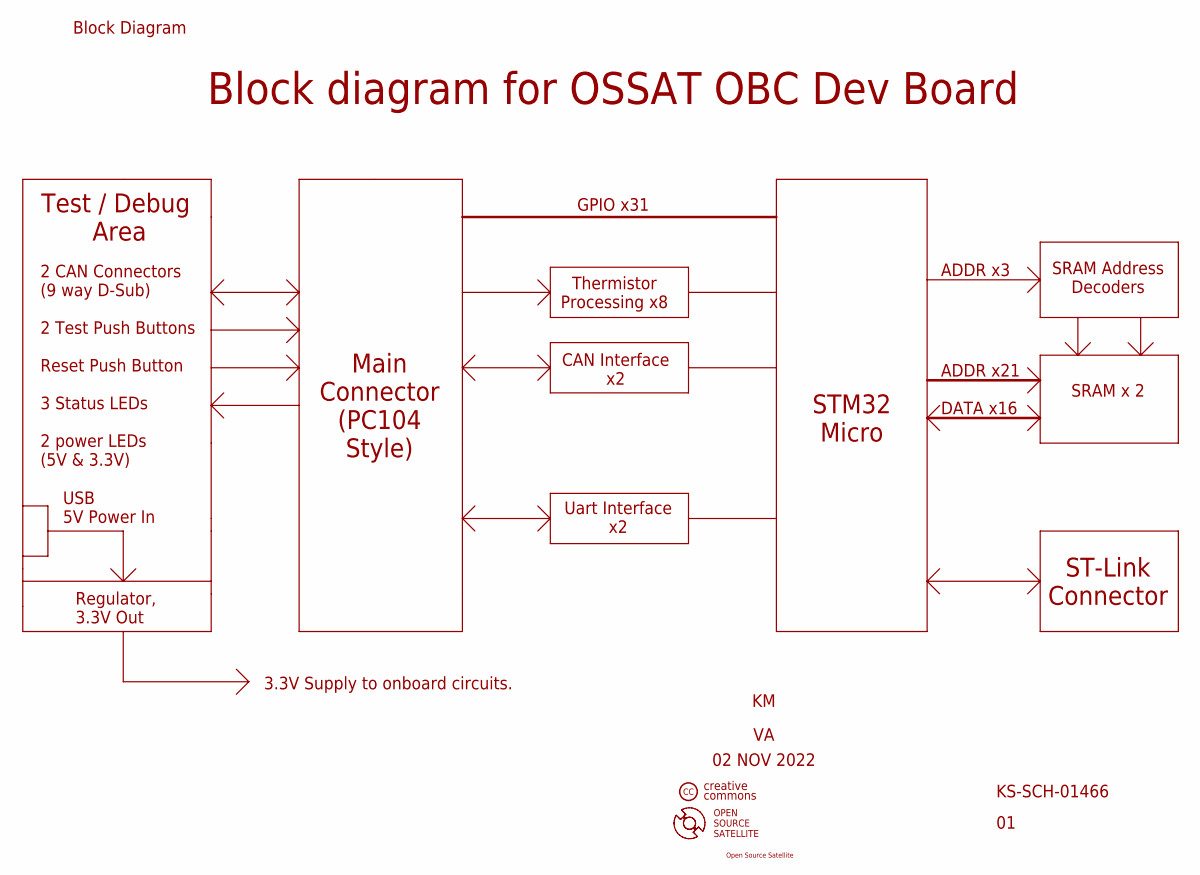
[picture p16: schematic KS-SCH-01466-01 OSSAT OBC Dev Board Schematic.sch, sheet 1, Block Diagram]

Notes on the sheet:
Block Diagram
Main Connector (PC104 Style)
STM32 Micro
Thermistor Processing x8
CAN Interface x2
Uart Interface x2
KS-SCH-01466
SRAM Address Decoders
SRAM x 2
ST-Link Connector
ADDR x21
DATA x16
ADDR x3
GPIO x31
Block diagram for OSSAT OBC Dev Board
02 NOV 2022
Test / Debug Area
Regulator, 3.3V Out
USB 5V Power In
3.3V Supply to onboard circuits.
2 CAN Connectors (9 way D-Sub) 2 Test Push Buttons Reset Push Button 3 Status LEDs 2 power LEDs (5V & 3.3V)
OPEN SOURCE SATELLITE
creative commons
Open Source Satellite

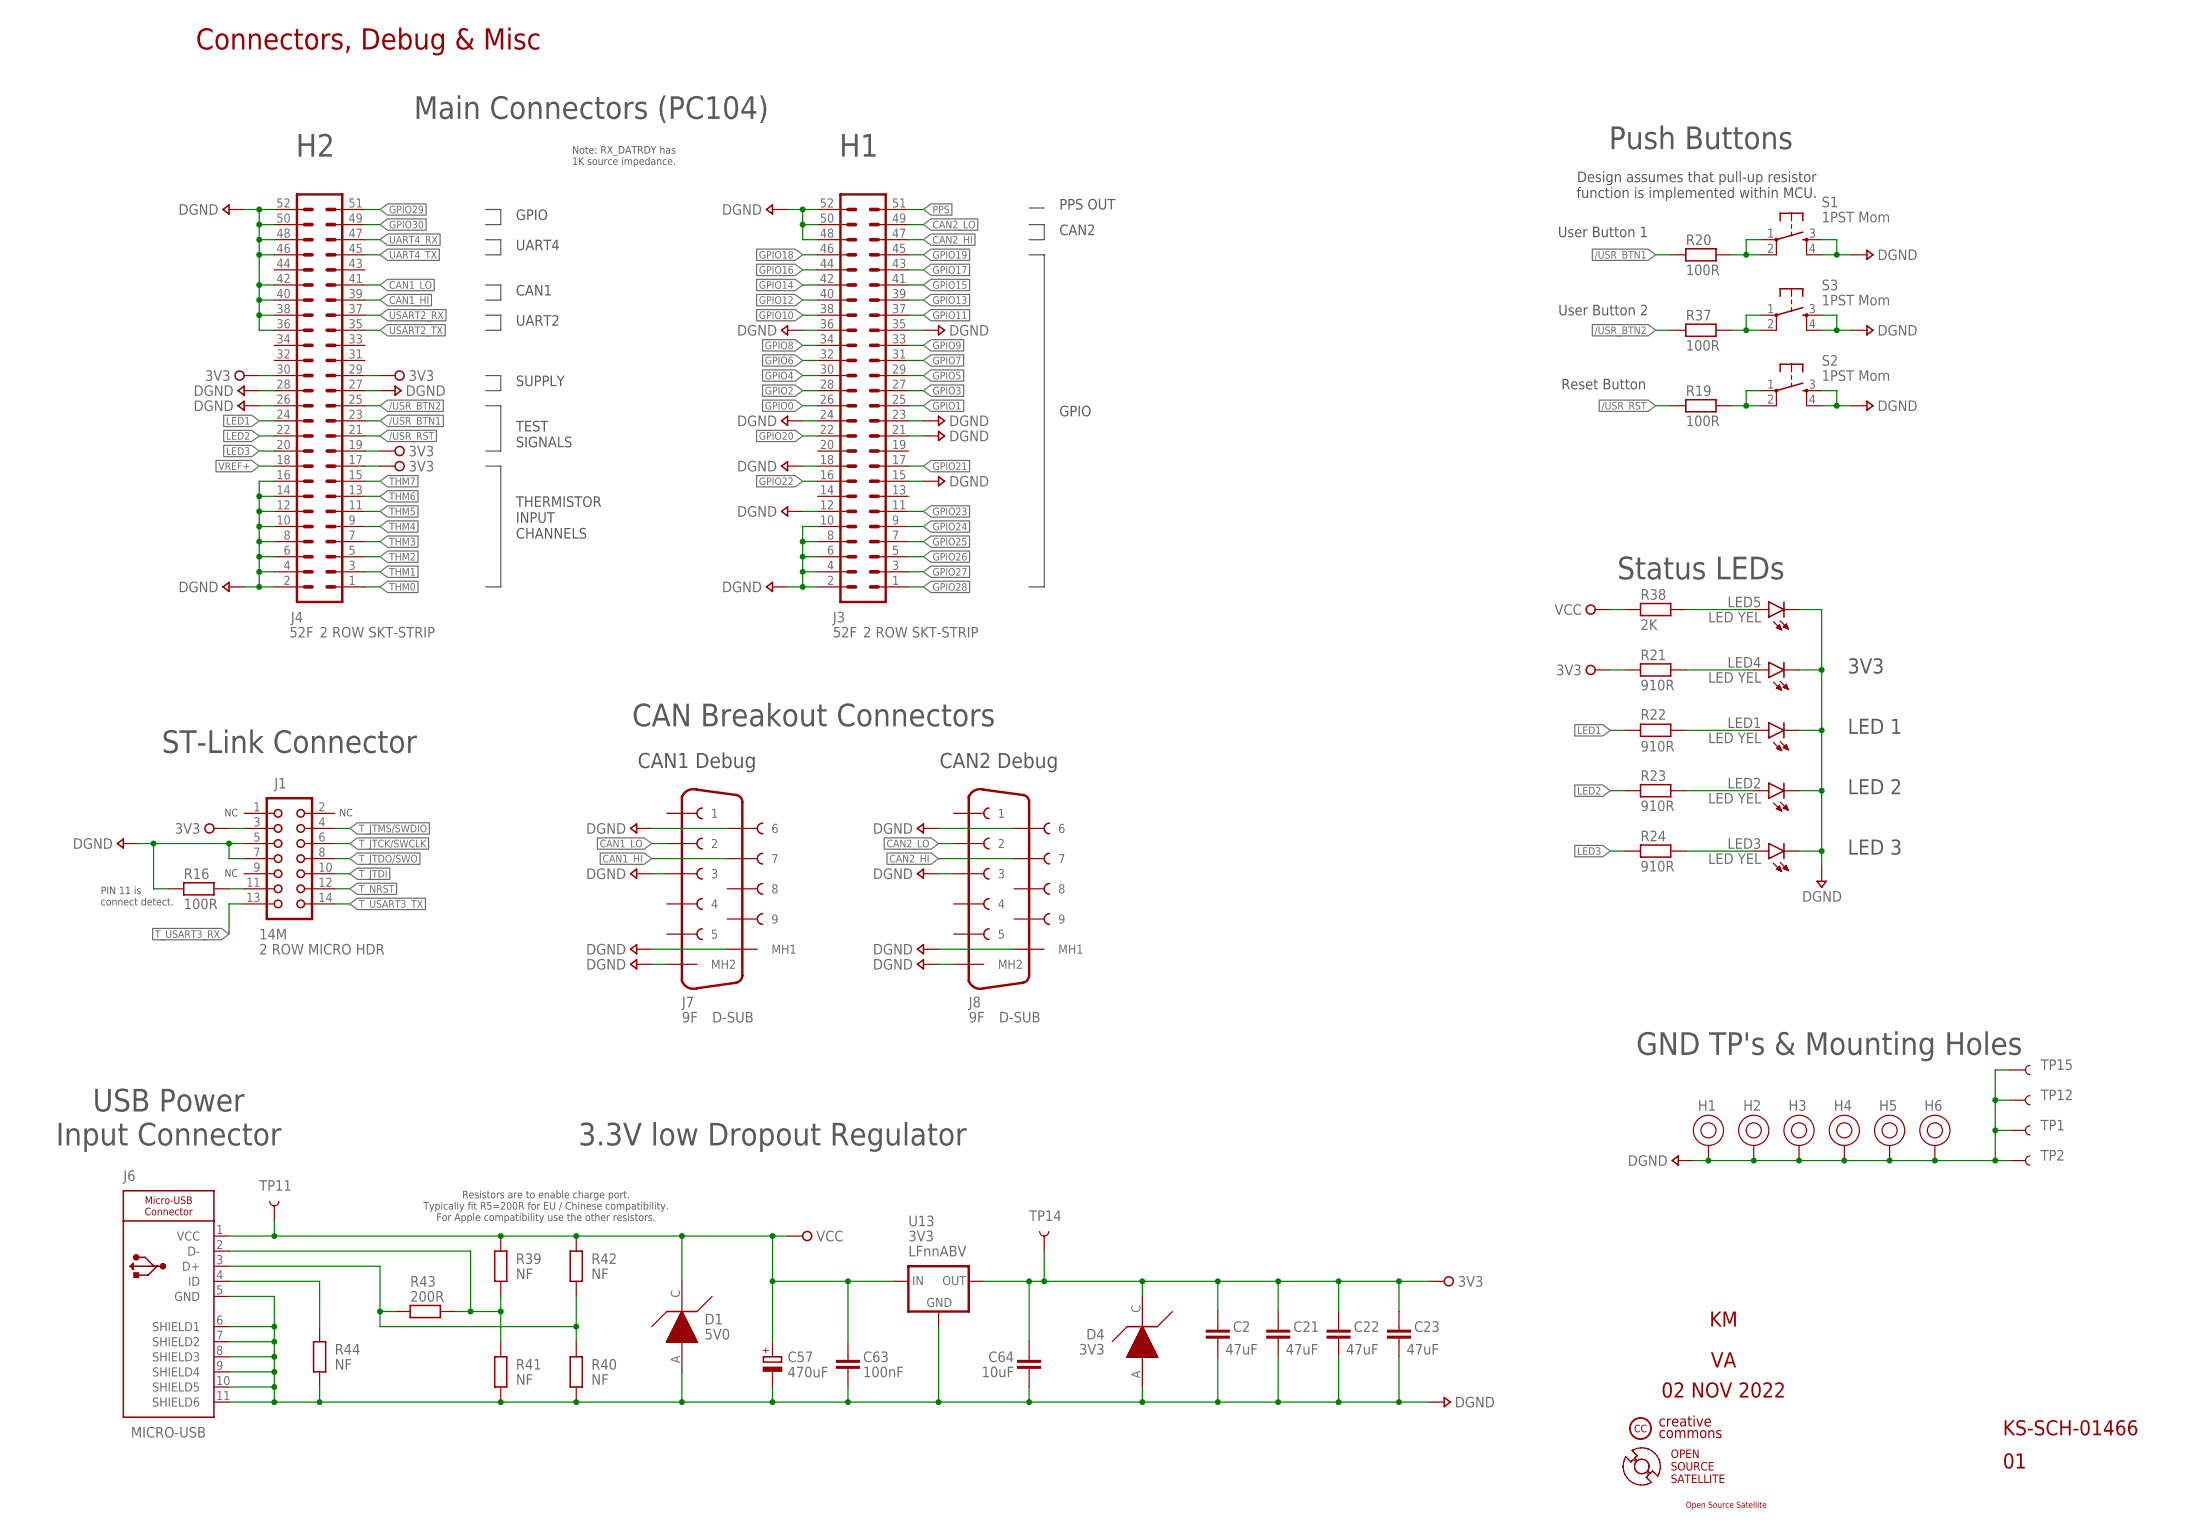
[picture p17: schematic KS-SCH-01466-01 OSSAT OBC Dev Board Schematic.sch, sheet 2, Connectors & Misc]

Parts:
C2, C21, C22, C23: 47uF; CAPC3225X135_1210
C57: 470uF; CAP_ELECT_RADIAL_D10_H12.5_P5
C63: 100nF; CAP_CHIP_0805
C64: 10uF; CAPC3225X135_1210
D1: 5V0; SOD323
D4: 3V3; SOD323
H1, H2, H3, H4, H5, H6: NF; HOLE-PTH-3.2-6.35
J1: 14M; HDRV14W41P127_2X7_FTSH
J3, J4: 52F; HDRVR52W64P254_2X26_6655X495X1105B
J6: CNRP105A_MICRO-USB_90DEG; CON_MICRO_USB_FEMALE
J7, J8: 9F; LD09S24A4GV00LF
LED1, LED2, LED3, LED4, LED5: OPTL102A_LED_YELLOW_0805_120DEG; LED_CHIP_0805
R16, R19, R20, R37: 100R; RES_CHIP_0805
R21, R22, R23, R24: 910R; RES_CHIP_0805
R38: 2K; RES_CHIP_0805
R39, R40, R41, R42, R44: NF; RES_CHIP_0805
R43: 200R; RES_CHIP_0805
S1, S2, S3: SWTA100A_1PST_SMD_MOMENTARY_PUSH-BUTTON; TACTILE_SWITCH_SMD_5.2MM
TP1, TP2, TP11, TP12, TP14, TP15: NF; TP-40TH
U13: 3V3; TO220L1A

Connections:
3V3: C2.1, C21.1, C22.1, C23.1, C64.1, D4.C (K), J1.3, J4.17, J4.19, J4.29, J4.30, R21.1, TP14.P$1, U13.3 (OUT); also elsewhere on the board
/USR_BTN1: J4.23, R20.2; also elsewhere on the board
/USR_BTN2: J4.25, R37.2; also elsewhere on the board
/USR_RST: J4.21, R19.2; also elsewhere on the board
CAN1_HI: J4.39, J7.7; also elsewhere on the board
CAN1_LO: J4.41, J7.2; also elsewhere on the board
CAN2_HI: J3.47, J8.7; also elsewhere on the board
CAN2_LO: J3.49, J8.2; also elsewhere on the board
DGND: C2.2, C21.2, C22.2, C23.2, C57.2 (-), C63.2, C64.2, D1.A, D4.A, H1.P$1, H2.P$1, H3.P$1, H4.P$1, H5.P$1, H6.P$1, J1.5, J1.7, J3.2, J3.4, J3.6, J3.8, J3.10, J3.12, J3.15, J3.18, J3.21, J3.23, J3.24, J3.35, J3.36, J3.48, J3.50, J3.52, J4.2, J4.4, J4.6, J4.8, J4.10, J4.12, J4.14, J4.16, J4.26, J4.27, J4.28, J4.36, J4.38, J4.40, J4.42, J4.46, J4.48, J4.50, J4.52, J6.5 (GND), J6.6 (SHIELD1), J6.7 (SHIELD2), J6.8 (SHIELD3), J6.9 (SHIELD4), J6.10 (SHIELD5), J6.11 (SHIELD6), J7.3, J7.6, J7.MH1 (MH2), J7.MH2 (MH1), J8.3, J8.6, J8.MH1 (MH2), J8.MH2 (MH1), LED1.C, LED2.C, LED3.C, LED4.C, LED5.C, R16.1, R40.1, R41.1, R44.1, S1.3, S1.4, S2.3, S2.4, S3.3, S3.4, TP1.P$1, TP2.P$1, TP12.P$1, TP15.P$1, U13.2 (GND); also elsewhere on the board
GPIO0: J3.26; also elsewhere on the board
GPIO1: J3.25; also elsewhere on the board
GPIO2: J3.28; also elsewhere on the board
GPIO3: J3.27; also elsewhere on the board
GPIO4: J3.30; also elsewhere on the board
GPIO5: J3.29; also elsewhere on the board
GPIO6: J3.32; also elsewhere on the board
GPIO7: J3.31; also elsewhere on the board
GPIO8: J3.34; also elsewhere on the board
GPIO9: J3.33; also elsewhere on the board
GPIO10: J3.38; also elsewhere on the board
GPIO11: J3.37; also elsewhere on the board
GPIO12: J3.40; also elsewhere on the board
GPIO13: J3.39; also elsewhere on the board
GPIO14: J3.42; also elsewhere on the board
GPIO15: J3.41; also elsewhere on the board
GPIO16: J3.44; also elsewhere on the board
GPIO17: J3.43; also elsewhere on the board
GPIO18: J3.46; also elsewhere on the board
GPIO19: J3.45; also elsewhere on the board
GPIO20: J3.22; also elsewhere on the board
GPIO21: J3.17; also elsewhere on the board
GPIO22: J3.16; also elsewhere on the board
GPIO23: J3.11; also elsewhere on the board
GPIO24: J3.9; also elsewhere on the board
GPIO25: J3.7; also elsewhere on the board
GPIO26: J3.5; also elsewhere on the board
GPIO27: J3.3; also elsewhere on the board
GPIO28: J3.1; also elsewhere on the board
GPIO29: J4.51; also elsewhere on the board
GPIO30: J4.49; also elsewhere on the board
LED1: J4.24, R22.1; also elsewhere on the board
LED2: J4.22, R23.1; also elsewhere on the board
LED3: J4.20, R24.1; also elsewhere on the board
unnamed: R19.1, S2.1, S2.2
unnamed: J1.11, R16.2
unnamed: R20.1, S1.1, S1.2
unnamed: LED4.A, R21.2
unnamed: LED1.A, R22.2
unnamed: LED2.A, R23.2
unnamed: LED3.A, R24.2
unnamed: R37.1, S3.1, S3.2
unnamed: LED5.A, R38.2
unnamed: J6.3 (D+), R40.2, R42.1, R43.1
unnamed: J6.2 (D-), R39.1, R41.2, R43.2
unnamed: J6.4 (ID), R44.2
PPS: J3.51; also elsewhere on the board
THM0: J4.1; also elsewhere on the board
THM1: J4.3; also elsewhere on the board
THM2: J4.5; also elsewhere on the board
THM3: J4.7; also elsewhere on the board
THM4: J4.9; also elsewhere on the board
THM5: J4.11; also elsewhere on the board
THM6: J4.13; also elsewhere on the board
THM7: J4.15; also elsewhere on the board
T_JTCK/SWCLK: J1.6; also elsewhere on the board
T_JTDI: J1.10; also elsewhere on the board
T_JTDO/SWO: J1.8; also elsewhere on the board
T_JTMS/SWDIO: J1.4; also elsewhere on the board
T_NRST: J1.12; also elsewhere on the board
T_USART3_RX: J1.13; also elsewhere on the board
T_USART3_TX: J1.14; also elsewhere on the board
UART4_RX: J4.47; also elsewhere on the board
UART4_TX: J4.45; also elsewhere on the board
USART2_RX: J4.37; also elsewhere on the board
USART2_TX: J4.35; also elsewhere on the board
VCC: C57.1 (+), C63.1, D1.C (K), J6.1 (VCC), R38.1, R39.2, R42.2, TP11.P$1, U13.1 (IN)
VREF+: J4.18; also elsewhere on the board

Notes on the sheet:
KS-SCH-01466
Connectors, Debug & Misc
ST-Link Connector
Main Connectors (PC104)
Note: RX_DATRDY has 1K source impedance.
PIN 11 is connect detect.
GND TP's & Mounting Holes
THERMISTOR INPUT CHANNELS
TEST SIGNALS
SUPPLY
CAN1
GPIO
CAN2
02 NOV 2022
CAN Breakout Connectors
CAN1 Debug
CAN2 Debug
3.3V low Dropout Regulator
Resistors are to enable charge port. Typically fit R5=200R for EU / Chinese compatibility. For Apple compatibility use the other resistors.
USB Power Input Connector
User Button 1
Reset Button
Status LEDs
3V3
LED 1
LED 2
LED 3
User Button 2
Push Buttons
Design assumes that pull-up resistor function is implemented within MCU.
UART4
UART2
PPS OUT
OPEN SOURCE SATELLITE
creative commons
Open Source Satellite

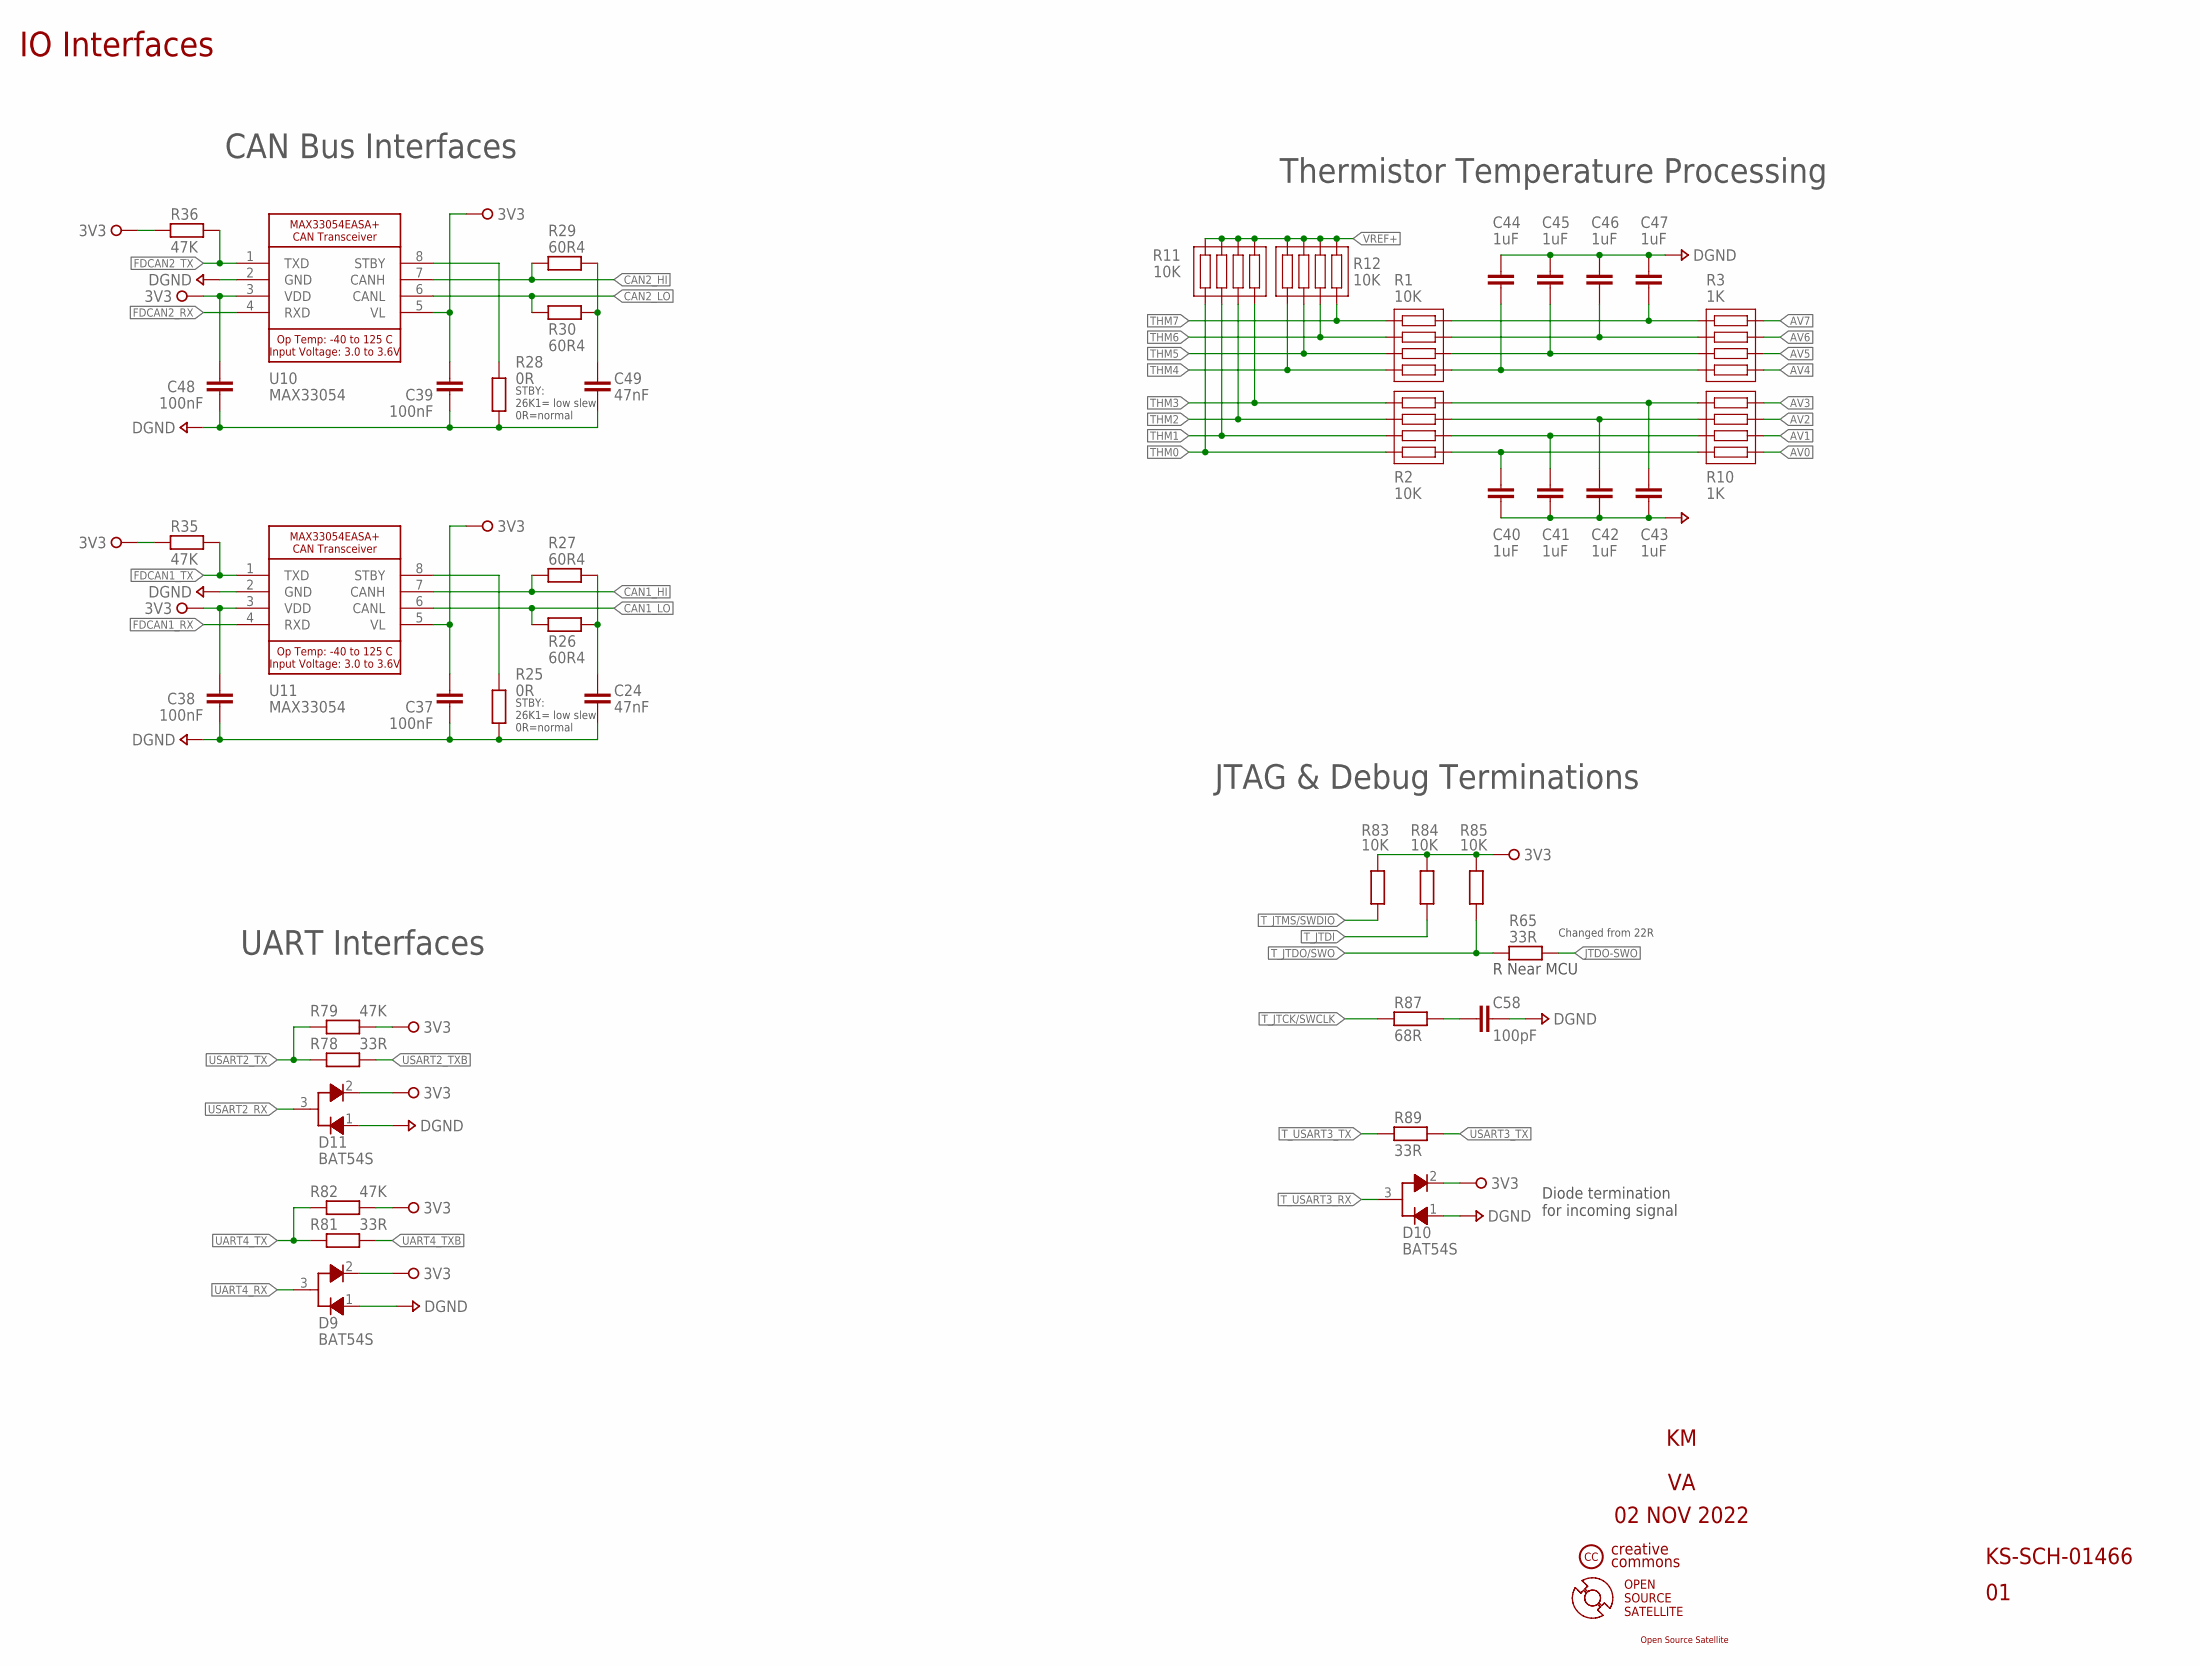
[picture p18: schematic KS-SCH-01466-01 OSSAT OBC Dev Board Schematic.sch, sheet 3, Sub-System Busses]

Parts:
C24, C49: 47nF; CAP_CHIP_0805
C37, C38, C39, C48: 100nF; CAP_CHIP_0805
C40, C41, C42, C43, C44, C45, C46, C47: 1uF; CAP_CHIP_0805
C58: 100pF; CAP_CHIP_0805
D9, D10, D11: DIOC100A_BAT54S_DUAL_SCHOTTKY; SOT23
R1, R2, R11, R12: 10K; RESCAXS80P320X160X60-8N
R3, R10: 1K; RESCAXS80P320X160X60-8N
R25, R28: 0R; RES_CHIP_0805
R26, R27, R29, R30: 60R4; RES_CHIP_0805
R35, R36, R79, R82: 47K; RES_CHIP_0805
R65, R78, R81, R89: 33R; RES_CHIP_0805
R83, R84, R85: 10K; RES_CHIP_0805
R87: 68R; RES_CHIP_0805
U10, U11: ICTT100A_MAX33054EASA+_CAN-TRANCEIVER; IC_MAX33054EASA+

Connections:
3V3: C37.2, C38.2, C39.2, C48.2, D9.2, D10.2, D11.2, R35.2, R36.2, R79.2, R82.2, R83.2, R84.2, R85.2, U10.3 (VDD), U10.5 (VL), U11.3 (VDD), U11.5 (VL); also elsewhere on the board
AV0: R10.5; also elsewhere on the board
AV1: R10.6; also elsewhere on the board
AV2: R10.7; also elsewhere on the board
AV3: R10.8; also elsewhere on the board
AV4: R3.5; also elsewhere on the board
AV5: R3.6; also elsewhere on the board
AV6: R3.7; also elsewhere on the board
AV7: R3.8; also elsewhere on the board
CAN1_HI: R27.1, U11.7 (CANH); also elsewhere on the board
CAN1_LO: R26.1, U11.6 (CANL); also elsewhere on the board
CAN2_HI: R29.1, U10.7 (CANH); also elsewhere on the board
CAN2_LO: R30.1, U10.6 (CANL); also elsewhere on the board
DGND: C24.1, C37.1, C38.1, C39.1, C40.2, C41.2, C42.2, C43.2, C44.1, C45.1, C46.1, C47.1, C48.1, C49.1, C58.2, D9.1, D10.1, D11.1, R25.1, R28.1, U10.2 (GND), U11.2 (GND); also elsewhere on the board
FDCAN1_RX: U11.4 (RXD); also elsewhere on the board
FDCAN1_TX: R35.1, U11.1 (TXD); also elsewhere on the board
FDCAN2_RX: U10.4 (RXD); also elsewhere on the board
FDCAN2_TX: R36.1, U10.1 (TXD); also elsewhere on the board
JTDO-SWO: R65.2; also elsewhere on the board
L_CSN+1: C40.1, R2.5, R10.4
L_CSN+10: C41.1, R2.6, R10.3
L_CSN+11: C42.1, R2.7, R10.2
L_CSN+12: C43.1, R2.8, R10.1
L_CSN+13: C44.2, R1.5, R3.4
L_CSN+14: C45.2, R1.6, R3.3
L_CSN+15: C46.2, R1.7, R3.2
L_CSN+16: C47.2, R1.8, R3.1
unnamed: C58.1, R87.2
unnamed: C24.2, R26.2, R27.2
unnamed: R25.2, U11.8 (STBY)
unnamed: R28.2, U10.8 (STBY)
unnamed: C49.2, R29.2, R30.2
THM0: R2.4, R11.5; also elsewhere on the board
THM1: R2.3, R11.6; also elsewhere on the board
THM2: R2.2, R11.7; also elsewhere on the board
THM3: R2.1, R11.8; also elsewhere on the board
THM4: R1.4, R12.5; also elsewhere on the board
THM5: R1.3, R12.6; also elsewhere on the board
THM6: R1.2, R12.7; also elsewhere on the board
THM7: R1.1, R12.8; also elsewhere on the board
T_JTCK/SWCLK: R87.1; also elsewhere on the board
T_JTDI: R84.1; also elsewhere on the board
T_JTDO/SWO: R65.1, R85.1; also elsewhere on the board
T_JTMS/SWDIO: R83.1; also elsewhere on the board
T_USART3_RX: D10.3; also elsewhere on the board
T_USART3_TX: R89.1; also elsewhere on the board
UART4_RX: D9.3; also elsewhere on the board
UART4_TX: R81.1, R82.1; also elsewhere on the board
UART4_TXB: R81.2; also elsewhere on the board
USART2_RX: D11.3; also elsewhere on the board
USART2_TX: R78.1, R79.1; also elsewhere on the board
USART2_TXB: R78.2; also elsewhere on the board
USART3_TX: R89.2; also elsewhere on the board
VREF+: R11.1, R11.2, R11.3, R11.4, R12.1, R12.2, R12.3, R12.4; also elsewhere on the board

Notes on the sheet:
IO Interfaces
STBY: 26K1= low slew 0R=normal
CAN Bus Interfaces
UART Interfaces
KS-SCH-01466
02 NOV 2022
Thermistor Temperature Processing
JTAG & Debug Terminations
R Near MCU
Diode termination for incoming signal
Changed from 22R
OPEN SOURCE SATELLITE
creative commons
Open Source Satellite

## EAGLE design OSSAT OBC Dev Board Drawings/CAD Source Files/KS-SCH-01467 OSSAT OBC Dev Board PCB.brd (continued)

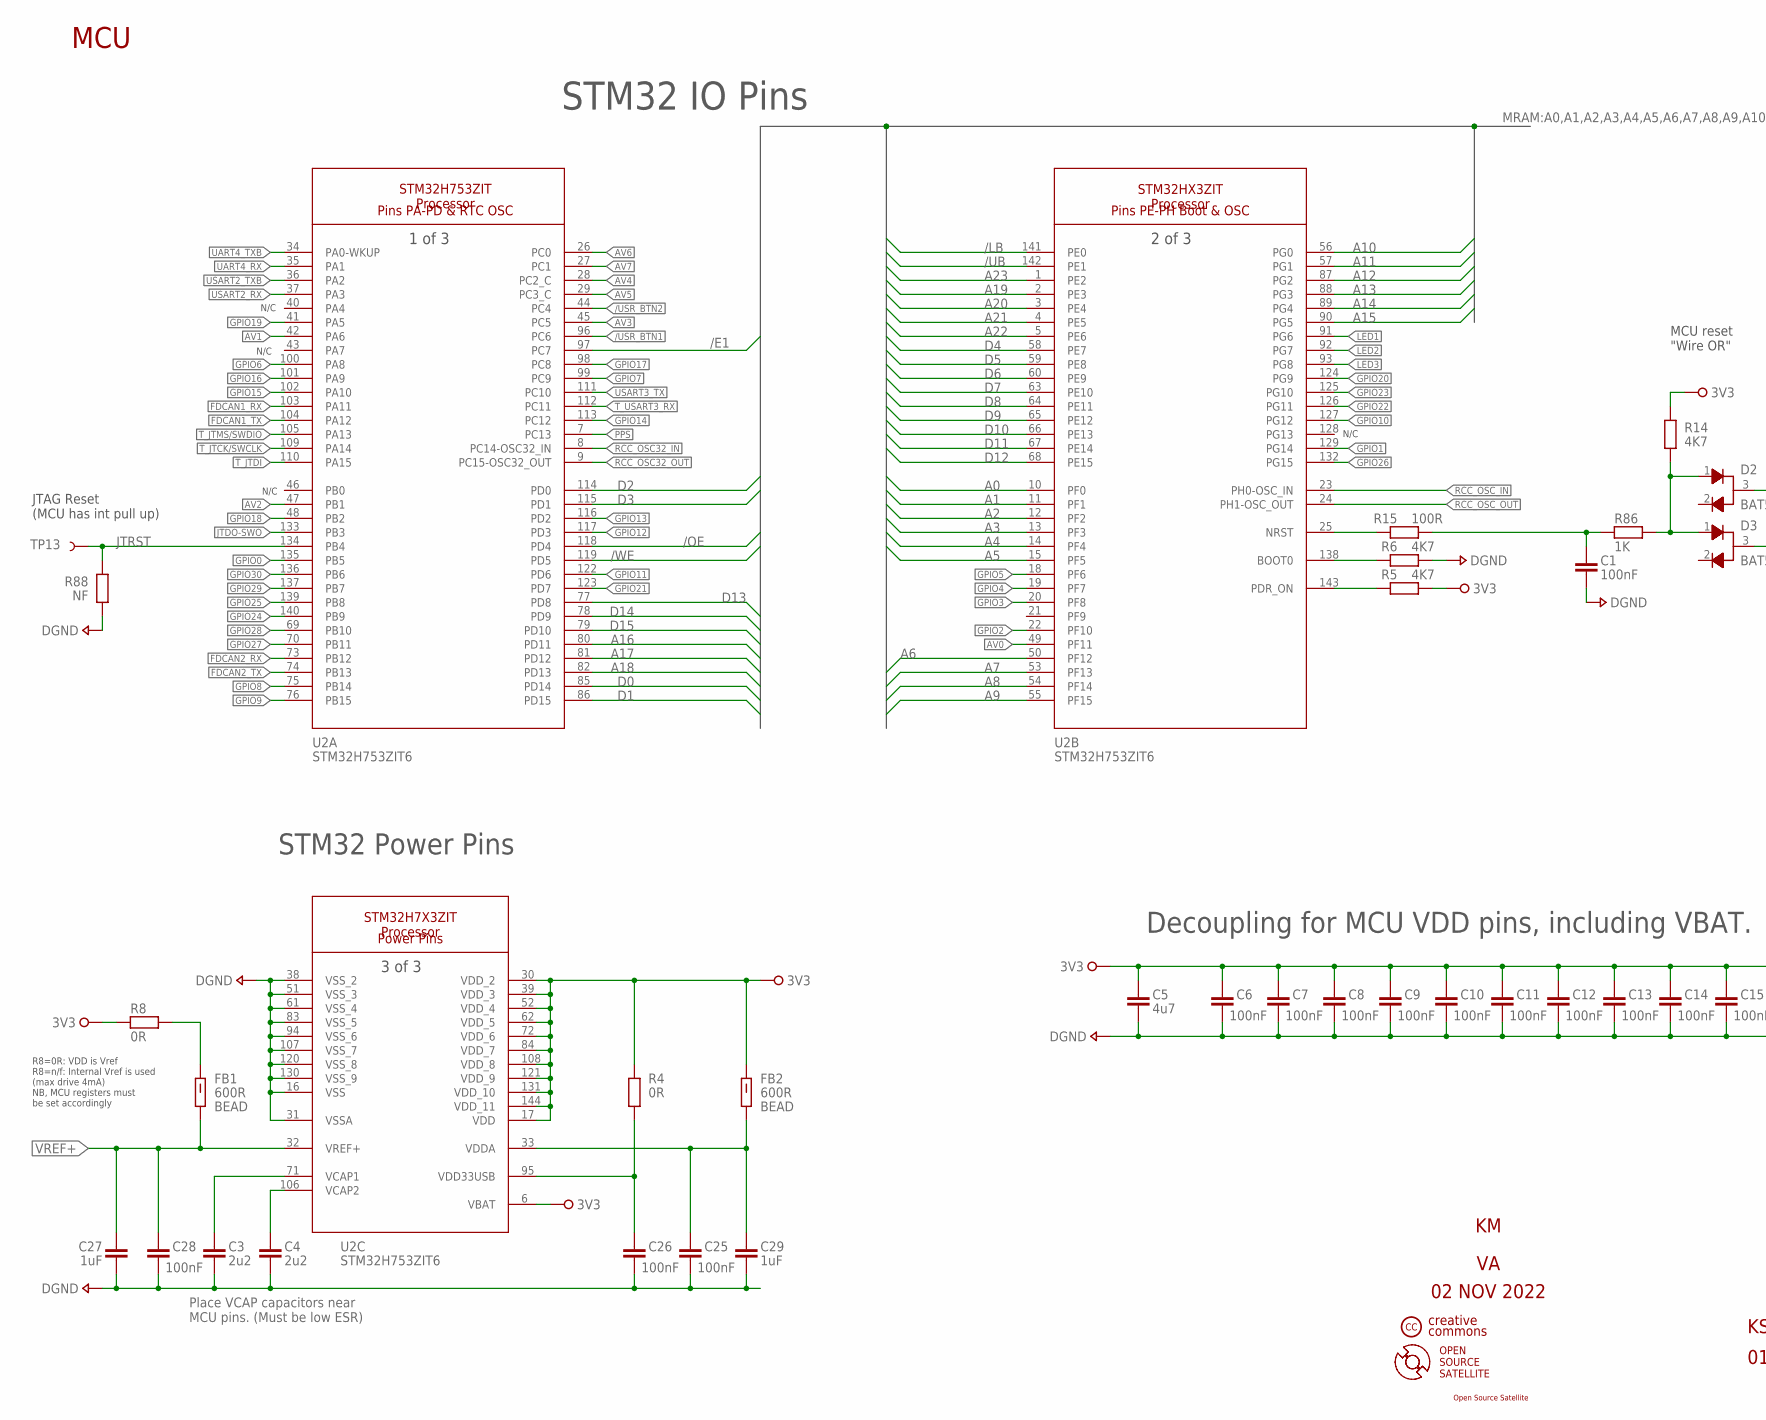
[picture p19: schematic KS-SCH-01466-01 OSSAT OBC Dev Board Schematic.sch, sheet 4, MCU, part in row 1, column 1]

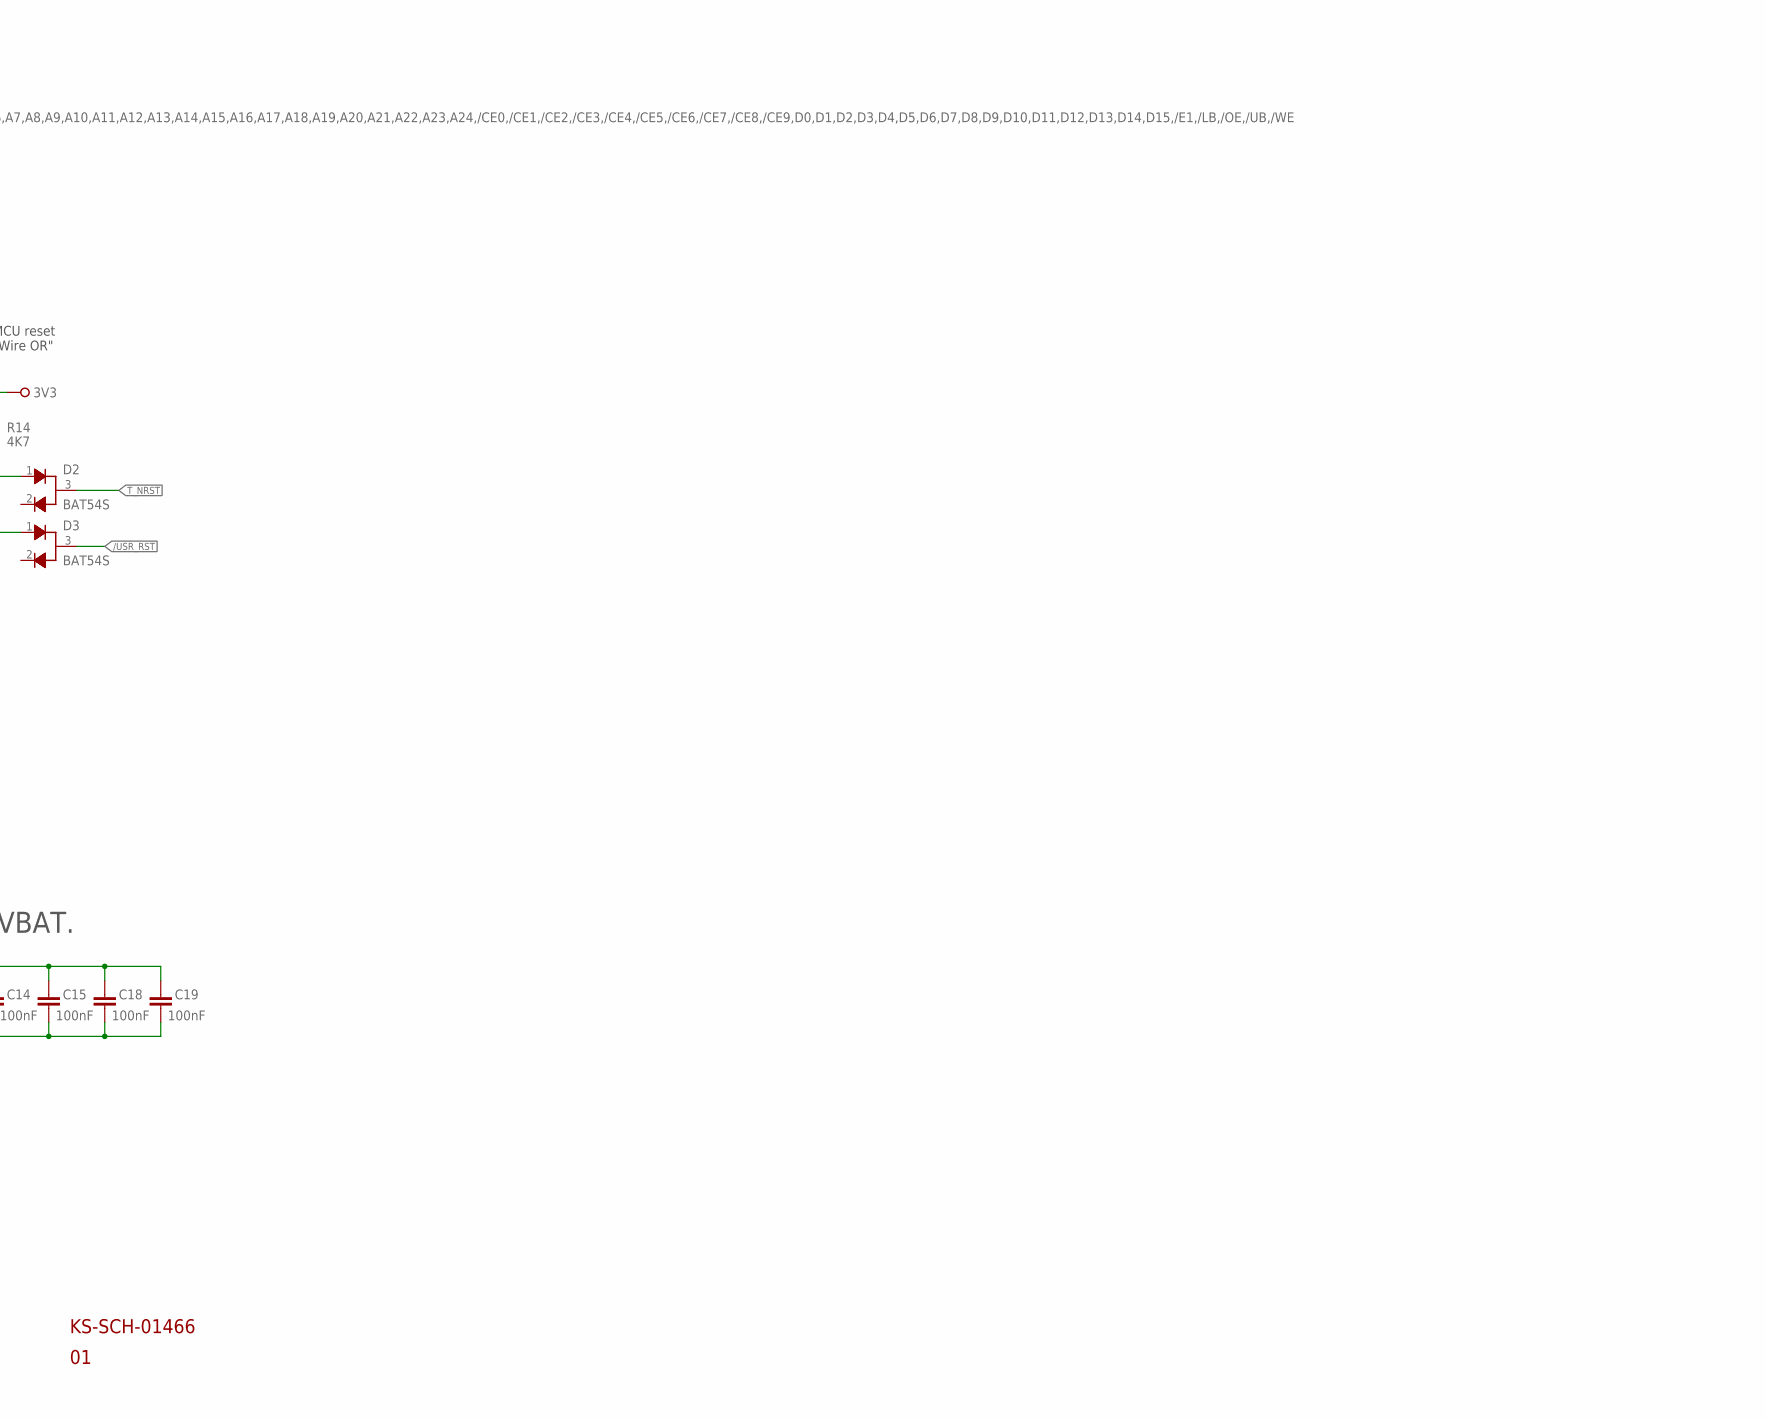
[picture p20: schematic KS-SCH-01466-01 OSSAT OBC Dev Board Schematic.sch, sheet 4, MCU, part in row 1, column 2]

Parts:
C1, C6, C7, C8, C9, C10, C11, C12, C13, C14, C15, C18, C19, C25, C26, C28: 100nF; CAP_CHIP_0805
C3, C4: 2u2; CAP_CHIP_0805
C5: 4u7; CAP_CHIP_0805
C27, C29: 1uF; CAP_CHIP_0805
D2, D3: DIOC100A_BAT54S_DUAL_SCHOTTKY; SOT23
FB1, FB2: 600R; BEADC2012X105N
R4, R8: 0R; RES_CHIP_0805
R5, R6, R14: 4K7; RES_CHIP_0805
R15: 100R; RES_CHIP_0805
R86: 1K; RES_CHIP_0805
R88: NF; RES_CHIP_0805
TP13: NF; TP-40TH
U2: ICTP100A_STM32H753ZIT6_MCU_144PIN; IC_STM32H753ZIT6

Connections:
3V3: C5.1, C6.1, C7.1, C8.1, C9.1, C10.1, C11.1, C12.1, C13.1, C14.1, C15.1, C18.1, C19.1, FB2.2, R4.2, R5.1, R8.2, R14.1, U2.6 (VBAT), U2.17 (VDD), U2.30 (VDD_2), U2.39 (VDD_3), U2.52 (VDD_4), U2.62 (VDD_5), U2.72 (VDD_6), U2.84 (VDD_7), U2.108 (VDD_8), U2.121 (VDD_9), U2.131 (VDD_10), U2.144 (VDD_11); also elsewhere on the board
/E1: U2.97 (PC7); also elsewhere on the board
/LB: U2.141 (PE0); also elsewhere on the board
/OE: U2.118 (PD4); also elsewhere on the board
/UB: U2.142 (PE1); also elsewhere on the board
/USR_BTN1: U2.96 (PC6); also elsewhere on the board
/USR_BTN2: U2.44 (PC4); also elsewhere on the board
/USR_RST: D3.3; also elsewhere on the board
/WE: U2.119 (PD5); also elsewhere on the board
A0: U2.10 (PF0); also elsewhere on the board
A1: U2.11 (PF1); also elsewhere on the board
A2: U2.12 (PF2); also elsewhere on the board
A3: U2.13 (PF3); also elsewhere on the board
A4: U2.14 (PF4); also elsewhere on the board
A5: U2.15 (PF5); also elsewhere on the board
A6: U2.50 (PF12); also elsewhere on the board
A7: U2.53 (PF13); also elsewhere on the board
A8: U2.54 (PF14); also elsewhere on the board
A9: U2.55 (PF15); also elsewhere on the board
A10: U2.56 (PG0); also elsewhere on the board
A11: U2.57 (PG1); also elsewhere on the board
A12: U2.87 (PG2); also elsewhere on the board
A13: U2.88 (PG3); also elsewhere on the board
A14: U2.89 (PG4); also elsewhere on the board
A15: U2.90 (PG5); also elsewhere on the board
A16: U2.80 (PD11); also elsewhere on the board
A17: U2.81 (PD12); also elsewhere on the board
A18: U2.82 (PD13); also elsewhere on the board
A19: U2.2 (PE3); also elsewhere on the board
A20: U2.3 (PE4); also elsewhere on the board
A21: U2.4 (PE5); also elsewhere on the board
A22: U2.5 (PE6); also elsewhere on the board
A23: U2.1 (PE2); also elsewhere on the board
AV0: U2.49 (PF11); also elsewhere on the board
AV1: U2.42 (PA6); also elsewhere on the board
AV2: U2.47 (PB1); also elsewhere on the board
AV3: U2.45 (PC5); also elsewhere on the board
AV4: U2.28 (PC2_C); also elsewhere on the board
AV5: U2.29 (PC3_C); also elsewhere on the board
AV6: U2.26 (PC0); also elsewhere on the board
AV7: U2.27 (PC1); also elsewhere on the board
BOOT0: R6.2, U2.138 (BOOT0)
D0: U2.85 (PD14); also elsewhere on the board
D1: U2.86 (PD15); also elsewhere on the board
D2: U2.114 (PD0); also elsewhere on the board
D3: U2.115 (PD1); also elsewhere on the board
D4: U2.58 (PE7); also elsewhere on the board
D5: U2.59 (PE8); also elsewhere on the board
D6: U2.60 (PE9); also elsewhere on the board
D7: U2.63 (PE10); also elsewhere on the board
D8: U2.64 (PE11); also elsewhere on the board
D9: U2.65 (PE12); also elsewhere on the board
D10: U2.66 (PE13); also elsewhere on the board
D11: U2.67 (PE14); also elsewhere on the board
D12: U2.68 (PE15); also elsewhere on the board
D13: U2.77 (PD8); also elsewhere on the board
D14: U2.78 (PD9); also elsewhere on the board
D15: U2.79 (PD10); also elsewhere on the board
DGND: C1.2, C3.2, C4.2, C5.2, C6.2, C7.2, C8.2, C9.2, C10.2, C11.2, C12.2, C13.2, C14.2, C15.2, C18.2, C19.2, C25.2, C26.2, C27.2, C28.2, C29.2, R6.1, R88.1, U2.16 (VSS), U2.31 (VSSA), U2.38 (VSS_2), U2.51 (VSS_3), U2.61 (VSS_4), U2.83 (VSS_5), U2.94 (VSS_6), U2.107 (VSS_7), U2.120 (VSS_8), U2.130 (VSS_9); also elsewhere on the board
FDCAN1_RX: U2.103 (PA11); also elsewhere on the board
FDCAN1_TX: U2.104 (PA12); also elsewhere on the board
FDCAN2_RX: U2.73 (PB12); also elsewhere on the board
FDCAN2_TX: U2.74 (PB13); also elsewhere on the board
GPIO0: U2.135 (PB5); also elsewhere on the board
GPIO1: U2.129 (PG14); also elsewhere on the board
GPIO2: U2.22 (PF10); also elsewhere on the board
GPIO3: U2.20 (PF8); also elsewhere on the board
GPIO4: U2.19 (PF7); also elsewhere on the board
GPIO5: U2.18 (PF6); also elsewhere on the board
GPIO6: U2.100 (PA8); also elsewhere on the board
GPIO7: U2.99 (PC9); also elsewhere on the board
GPIO8: U2.75 (PB14); also elsewhere on the board
GPIO9: U2.76 (PB15); also elsewhere on the board
GPIO10: U2.127 (PG12); also elsewhere on the board
GPIO11: U2.122 (PD6); also elsewhere on the board
GPIO12: U2.117 (PD3); also elsewhere on the board
GPIO13: U2.116 (PD2); also elsewhere on the board
GPIO14: U2.113 (PC12); also elsewhere on the board
GPIO15: U2.102 (PA10); also elsewhere on the board
GPIO16: U2.101 (PA9); also elsewhere on the board
GPIO17: U2.98 (PC8); also elsewhere on the board
GPIO18: U2.48 (PB2); also elsewhere on the board
GPIO19: U2.41 (PA5); also elsewhere on the board
GPIO20: U2.124 (PG9); also elsewhere on the board
GPIO21: U2.123 (PD7); also elsewhere on the board
GPIO22: U2.126 (PG11); also elsewhere on the board
GPIO23: U2.125 (PG10); also elsewhere on the board
GPIO24: U2.140 (PB9); also elsewhere on the board
GPIO25: U2.139 (PB8); also elsewhere on the board
GPIO26: U2.132 (PG15); also elsewhere on the board
GPIO27: U2.70 (PB11); also elsewhere on the board
GPIO28: U2.69 (PB10); also elsewhere on the board
GPIO29: U2.137 (PB7); also elsewhere on the board
GPIO30: U2.136 (PB6); also elsewhere on the board
JTDO-SWO: U2.133 (PB3); also elsewhere on the board
JTRST: R88.2, TP13.P$1, U2.134 (PB4)
LED1: U2.91 (PG6); also elsewhere on the board
LED2: U2.92 (PG7); also elsewhere on the board
LED3: U2.93 (PG8); also elsewhere on the board
unnamed: C26.1, R4.1, U2.95 (VDD33USB)
unnamed: FB1.2, R8.1
unnamed: C25.1, C29.1, FB2.1, U2.33 (VDDA)
unnamed: C4.1, U2.106 (VCAP2)
unnamed: C3.1, U2.71 (VCAP1)
unnamed: R15.2, U2.25 (NRST)
unnamed: D2.1, D3.1, R14.2, R86.2
unnamed: R5.2, U2.143 (PDR_ON)
unnamed: C1.1, R15.1, R86.1
PPS: U2.7 (PC13); also elsewhere on the board
RCC_OSC32_IN: U2.8 (PC14-OSC32_IN); also elsewhere on the board
RCC_OSC32_OUT: U2.9 (PC15-OSC32_OUT); also elsewhere on the board
RCC_OSC_IN: U2.23 (PH0-OSC_IN); also elsewhere on the board
RCC_OSC_OUT: U2.24 (PH1-OSC_OUT); also elsewhere on the board
T_JTCK/SWCLK: U2.109 (PA14); also elsewhere on the board
T_JTDI: U2.110 (PA15); also elsewhere on the board
T_JTMS/SWDIO: U2.105 (PA13); also elsewhere on the board
T_NRST: D2.3; also elsewhere on the board
T_USART3_RX: U2.112 (PC11); also elsewhere on the board
UART4_RX: U2.35 (PA1); also elsewhere on the board
UART4_TXB: U2.34 (PA0-WKUP); also elsewhere on the board
USART2_RX: U2.37 (PA3); also elsewhere on the board
USART2_TXB: U2.36 (PA2); also elsewhere on the board
USART3_TX: U2.111 (PC10); also elsewhere on the board
VREF+: C27.1, C28.1, FB1.1, U2.32 (VREF+); also elsewhere on the board

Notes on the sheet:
Decoupling for MCU VDD pins, including VBAT.
STM32 IO Pins
Place VCAP capacitors near MCU pins. (Must be low ESR)
STM32 Power Pins
R8=0R: VDD is Vref R8=n/f: Internal Vref is used (max drive 4mA) NB, MCU registers must be set accordingly
N/C
MCU reset "Wire OR"
KS-SCH-01466
MCU
02 NOV 2022
JTAG Reset (MCU has int pull up)
OPEN SOURCE SATELLITE
creative commons
Open Source Satellite

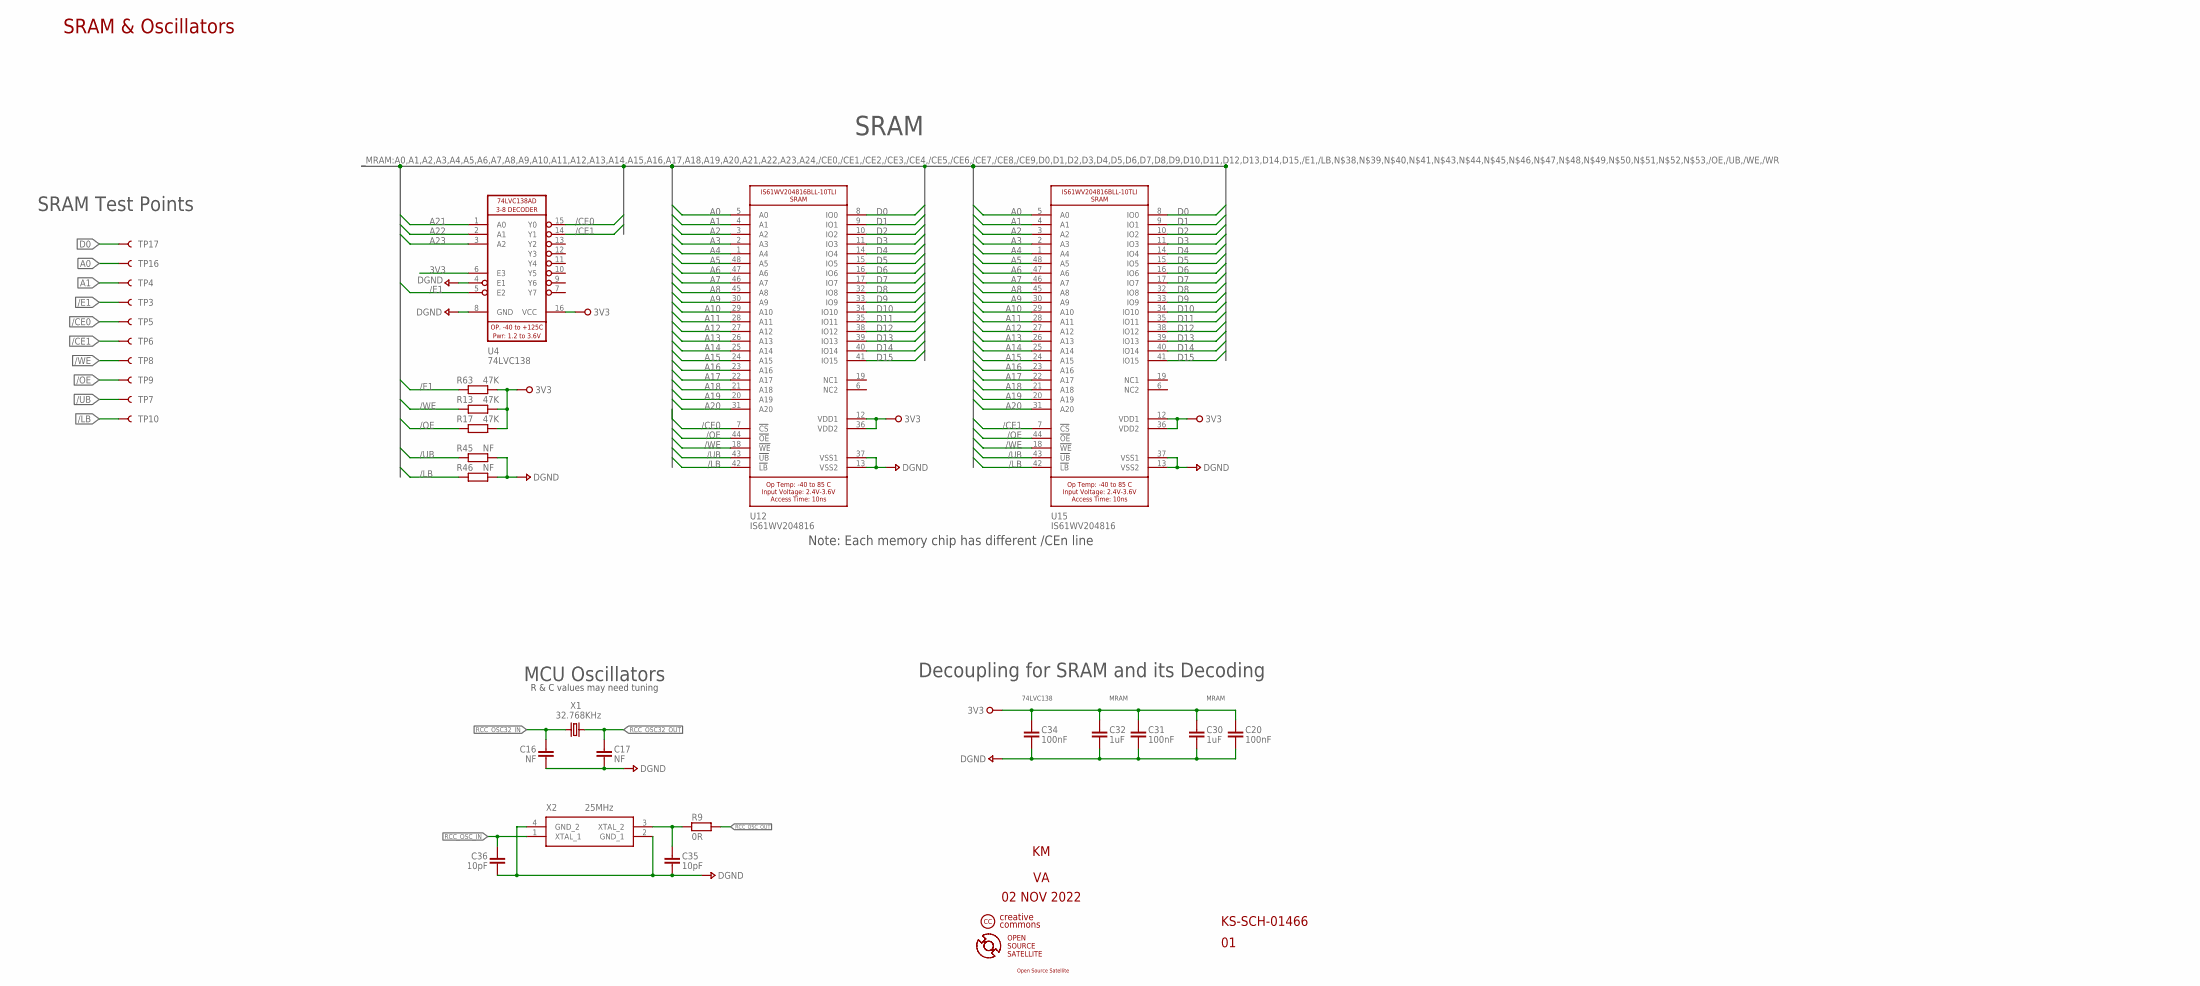
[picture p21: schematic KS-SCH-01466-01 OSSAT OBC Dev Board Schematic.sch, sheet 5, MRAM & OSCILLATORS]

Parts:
C16, C17: NF; CAP_CHIP_0805
C20, C31, C34: 100nF; CAP_CHIP_0805
C30, C32: 1uF; CAP_CHIP_0805
C35, C36: 10pF; CAP_CHIP_0805
R9: 0R; RES_CHIP_0805
R13, R17, R63: 47K; RES_CHIP_0805
R45, R46: NF; RES_CHIP_0805
TP3, TP4, TP5, TP6, TP7, TP8, TP9, TP10, TP16, TP17: NF; TP-40TH
U4: ICTL100A_74LVC138AD_3-8_DECODER; SOIC-16
U12, U15: ICTM101A_IS61WV204816BLL-10TLI_SRAM_4MBYTE; IS61WV204816BLL-10TLI
X1: OSCC100A_XTAL_32.768KHZ_12P5; XTAL_NX3215SA
X2: OSCC102A_XTAL_25MHZ_10PF; XTAL_NX2016SA

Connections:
3V3: C20.1, C30.1, C31.1, C32.1, C34.1, R13.2, R17.2, R63.2, U4.6 (E3), U4.16 (VCC), U12.12 (VDD1), U12.36 (VDD2), U15.12 (VDD1), U15.36 (VDD2); also elsewhere on the board
/CE0: TP5.P$1, U4.15 (Y0), U12.7 (!CS)
/CE1: TP6.P$1, U4.14 (Y1), U15.7 (!CS)
/E1: R63.1, TP3.P$1, U4.5 (E2); also elsewhere on the board
/LB: R46.1, TP10.P$1, U12.42 (!LB), U15.42 (!LB); also elsewhere on the board
/OE: R17.1, TP9.P$1, U12.44 (!OE), U15.44 (!OE); also elsewhere on the board
/UB: R45.1, TP7.P$1, U12.43 (!UB), U15.43 (!UB); also elsewhere on the board
/WE: R13.1, TP8.P$1, U12.18 (!WE), U15.18 (!WE); also elsewhere on the board
A0: TP16.P$1, U12.5 (A0), U15.5 (A0); also elsewhere on the board
A1: TP4.P$1, U12.4 (A1), U15.4 (A1); also elsewhere on the board
A2: U12.3 (A2), U15.3 (A2); also elsewhere on the board
A3: U12.2 (A3), U15.2 (A3); also elsewhere on the board
A4: U12.1 (A4), U15.1 (A4); also elsewhere on the board
A5: U12.48 (A5), U15.48 (A5); also elsewhere on the board
A6: U12.47 (A6), U15.47 (A6); also elsewhere on the board
A7: U12.46 (A7), U15.46 (A7); also elsewhere on the board
A8: U12.45 (A8), U15.45 (A8); also elsewhere on the board
A9: U12.30 (A9), U15.30 (A9); also elsewhere on the board
A10: U12.29 (A10), U15.29 (A10); also elsewhere on the board
A11: U12.28 (A11), U15.28 (A11); also elsewhere on the board
A12: U12.27 (A12), U15.27 (A12); also elsewhere on the board
A13: U12.26 (A13), U15.26 (A13); also elsewhere on the board
A14: U12.25 (A14), U15.25 (A14); also elsewhere on the board
A15: U12.24 (A15), U15.24 (A15); also elsewhere on the board
A16: U12.23 (A16), U15.23 (A16); also elsewhere on the board
A17: U12.22 (A17), U15.22 (A17); also elsewhere on the board
A18: U12.21 (A18), U15.21 (A18); also elsewhere on the board
A19: U12.20 (A19), U15.20 (A19); also elsewhere on the board
A20: U12.31 (A20), U15.31 (A20); also elsewhere on the board
A21: U4.1 (A0); also elsewhere on the board
A22: U4.2 (A1); also elsewhere on the board
A23: U4.3 (A2); also elsewhere on the board
D0: TP17.P$1, U12.8 (IO0), U15.8 (IO0); also elsewhere on the board
D1: U12.9 (IO1), U15.9 (IO1); also elsewhere on the board
D2: U12.10 (IO2), U15.10 (IO2); also elsewhere on the board
D3: U12.11 (IO3), U15.11 (IO3); also elsewhere on the board
D4: U12.14 (IO4), U15.14 (IO4); also elsewhere on the board
D5: U12.15 (IO5), U15.15 (IO5); also elsewhere on the board
D6: U12.16 (IO6), U15.16 (IO6); also elsewhere on the board
D7: U12.17 (IO7), U15.17 (IO7); also elsewhere on the board
D8: U12.32 (IO8), U15.32 (IO8); also elsewhere on the board
D9: U12.33 (IO9), U15.33 (IO9); also elsewhere on the board
D10: U12.34 (IO10), U15.34 (IO10); also elsewhere on the board
D11: U12.35 (IO11), U15.35 (IO11); also elsewhere on the board
D12: U12.38 (IO12), U15.38 (IO12); also elsewhere on the board
D13: U12.39 (IO13), U15.39 (IO13); also elsewhere on the board
D14: U12.40 (IO14), U15.40 (IO14); also elsewhere on the board
D15: U12.41 (IO15), U15.41 (IO15); also elsewhere on the board
DGND: C16.2, C17.2, C20.2, C30.2, C31.2, C32.2, C34.2, C35.2, C36.2, R45.2, R46.2, U4.4 (E1), U4.8 (GND), U12.13 (VSS2), U12.37 (VSS1), U15.13 (VSS2), U15.37 (VSS1), X2.2 (GND_1), X2.4 (GND_2); also elsewhere on the board
unnamed: C35.1, R9.2, X2.3 (XTAL_2)
RCC_OSC32_IN: C16.1, X1.2; also elsewhere on the board
RCC_OSC32_OUT: C17.1, X1.1; also elsewhere on the board
RCC_OSC_IN: C36.1, X2.1 (XTAL_1); also elsewhere on the board
RCC_OSC_OUT: R9.1; also elsewhere on the board

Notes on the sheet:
Note: Each memory chip has different /CEn line
SRAM
Decoupling for SRAM and its Decoding
74LVC138
MRAM
SRAM & Oscillators
KS-SCH-01466
SRAM Test Points
MCU Oscillators
R & C values may need tuning
02 NOV 2022
OPEN SOURCE SATELLITE
creative commons
Open Source Satellite

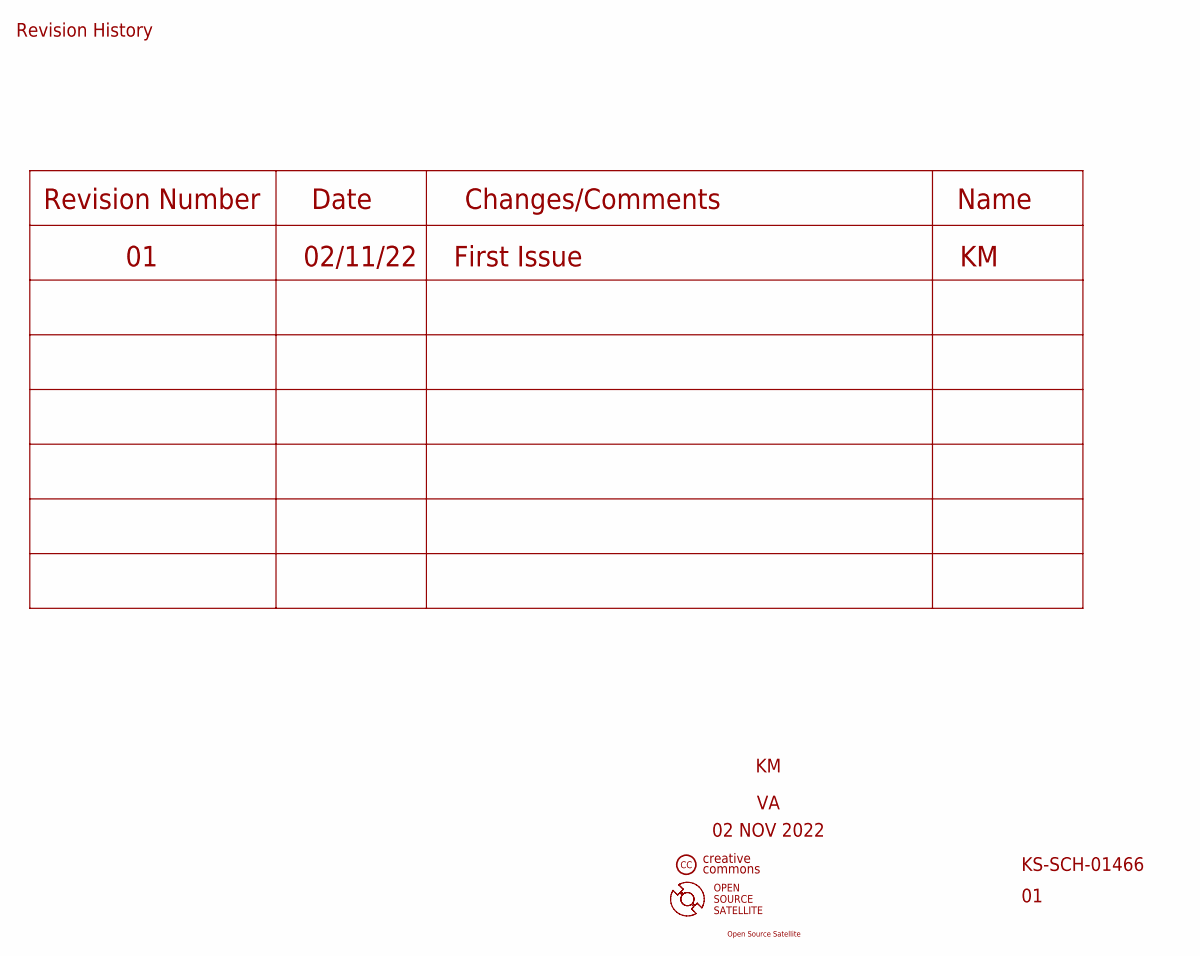
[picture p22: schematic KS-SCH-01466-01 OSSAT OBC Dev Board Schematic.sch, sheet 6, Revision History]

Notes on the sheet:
Revision History
KS-SCH-01466
Revision Number
Date
Changes/Comments
02/11/22
First Issue
Name
02 NOV 2022
OPEN SOURCE SATELLITE
creative commons
Open Source Satellite

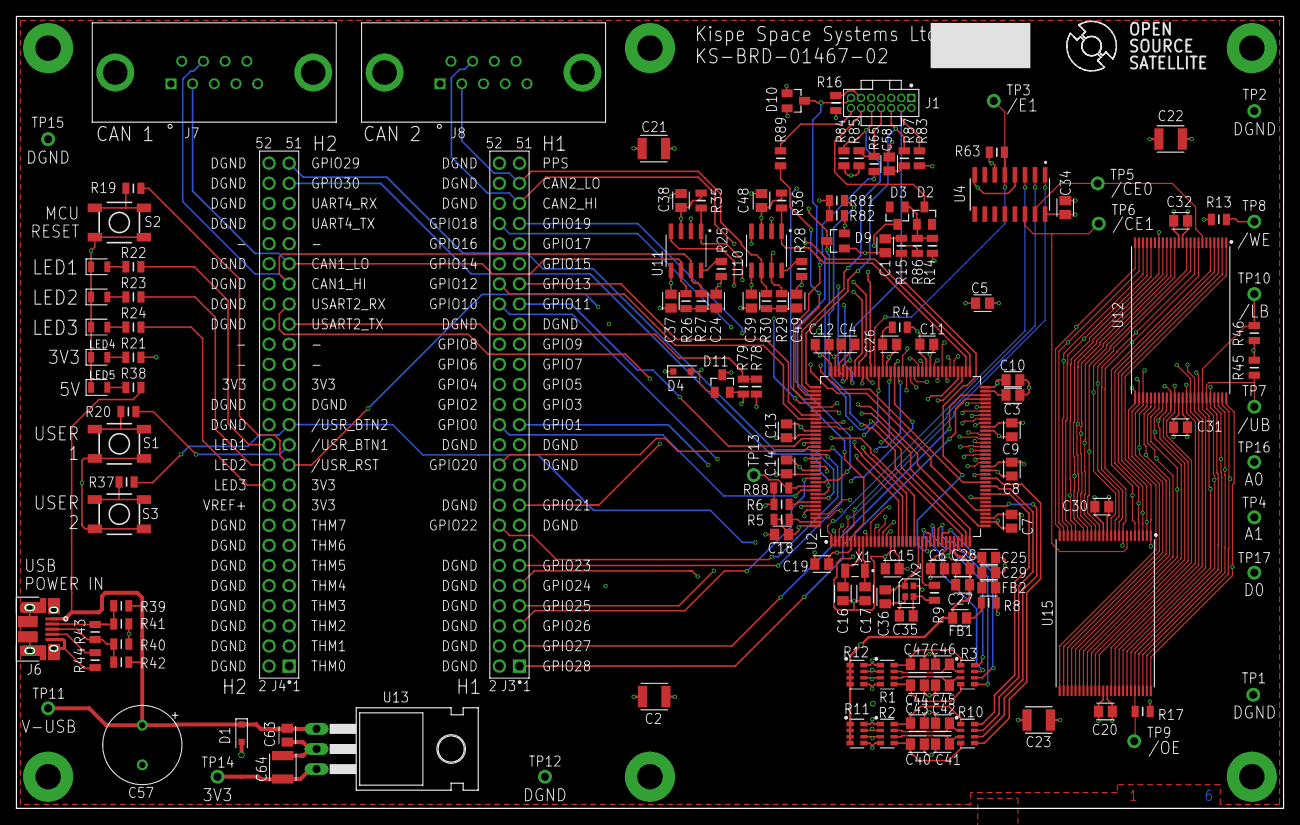
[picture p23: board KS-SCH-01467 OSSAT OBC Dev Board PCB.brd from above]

Board: 6 copper layers, 160.0 x 100.0 mm, 160 parts (0 on the bottom side), 169 nets.

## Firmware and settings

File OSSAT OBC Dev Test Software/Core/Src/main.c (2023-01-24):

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
/* Includes ------------------------------------------------------------------*/
#include "main.h"
#include "STM32CAN_ContollerAreaNetwork.h"

/**********************************
 * PRM: test buttons to LEDs:
 * One LED flash on off all the time
 * One user button does one LED
 * The other button does the other LED
 * PPS: remove the test.
 **********************************


 ADC_HandleTypeDef hadc1;
ADC_HandleTypeDef hadc3;

FDCAN_HandleTypeDef hfdcan1;
FDCAN_HandleTypeDef hfdcan2;

I2C_HandleTypeDef hi2c1;
I2C_HandleTypeDef hi2c2;
I2C_HandleTypeDef hi2c4;

RTC_HandleTypeDef hrtc;

SPI_HandleTypeDef hspi1;

UART_HandleTypeDef huart4;
UART_HandleTypeDef huart2;
UART_HandleTypeDef huart3;

SRAM_HandleTypeDef hsram1;

void SystemClock_Config(void);
static void MX_GPIO_Init(void);
static void MX_ADC1_Init(void);
static void MX_ADC3_Init(void);
static void MX_FDCAN1_Init(void);
static void MX_FDCAN2_Init(void);
static void MX_FMC_Init(void);
static void MX_I2C1_Init(void);
static void MX_I2C2_Init(void);
static void MX_SPI1_Init(void);
static void MX_UART4_Init(void);
static void MX_USART2_UART_Init(void);
static void MX_RTC_Init(void);
static void MX_USART3_UART_Init(void);
static void MX_I2C4_Init(void);
static void UART_Test(UART_HandleTypeDef *huart);
static void GPIO_Test(void);
static void ANALOGUE_Test(void);
static void LVDS_DR_To_MOSI_Test(void);
static void LVDS_DR_To_NSS_Test(void);
static void LVDS_DR_To_SCK_Test(void);
static void LVDS_EXTI9_To_MOSI_Test(void);
static void LVDS_EXTI9_To_NSS_Test(void);
static void LVDS_EXTI9_To_SCK_Test(void);
static void LoopBackIoTest(GPIO_TypeDef *InputGPIOx, uint16_t InputGPIO_Pin, GPIO_TypeDef *OutputGPIOx, uint16_t OutputGPIO_Pin);
static void CAN1_Test(void);
static void CAN2_Test(void);
static void MRAM_CSTest(void);
/* USER CODE BEGIN PFP */

#define MRAM_START_ADDRESS (0xC0000000UL)
#define MRAM_SIZE (0x7FFFFFUL)
#define MRAM_SINGLE_CHIP_SIZE (0x00400000UL)

/* USER CODE END PFP */

unsigned int HAL_RCC_FDCAN_CLK_ENABLED = 0;

char pcSplashScreen[] = "\r\n\r\n\r\n\r\n\r\n\r\n\r\n\r\n                  %@@@@@@@@@@@@@@@@@@@@@,\r\n"
"              (@@@@@@@@@@@@@@@@@@@@@@@@@@@@@@.\r\n"
"           @@@@@@@@@@@@@@@@@@@@@@@@@@@@@@@@\r\n"
"        *@@@@@@@@@@@@@@@@@@@@@@@@@@@@@@@,\r\n"
"      (@@@@@@@@@@@@@@@@@@@@@@@@@@@@@@@\r\n"
"     @@@@@@@@@@@@@@@@@@@@@@@@@@@@@@@@@@@               @\r\n"
"   *@@@@@@@@@@@@@@@@@@@@@@@@@@@@@@@@@@@@@            @@@@\r\n"
"  /@@@@@@@@@@@@@@@@@@@@@#           @@/   @@@     @@@@@@@@\r\n"
"  @@@@@@@@@@@@@@@@@@@&                  @@@@@@@*@@@@@@@@@@@\r\n"
" @@@@@@@@@@@@@@@@@@@                     @@@@@@@@@@@@@@@@@@&\r\n"
" @@@@@@@@@@@@@@@@@@                       @@@@@@@@@@@@@@@@@@\r\n"
" @@@@@@@@@@@@@@@@@@                       @@@@@@@@@@@@@@@@@@\r\n"
" @@@@@@@@@@@@@@@@@@                       @@@@@@@@@@@@@@@@@@\r\n"
" @@@@@@@@@@@@@@@@@@@                     @@@@@@@@@@@@@@@@@@&\r\n"
"  @@@@@@@@@@@@@@@@@@@                  @@@@@@@@@@@@@@@@@@@@\r\n"
"  *@@@@@@@,     @@*   @@&           @@@@@@@@@@@@@@@@@@@@@@\r\n"
"   ,@@@@            @@@@@@@@@@@@@@@@@@@@@@@@@@@@@@@@@@@@@\r\n"
"     .               @@@@@@@@@@@@@@@@@@@@@@@@@@@@@@@@@@@\r\n"
"                       @@@@@@@@@@@@@@@@@@@@@@@@@@@@@@@\r\n"
"                    @@@@@@@@@@@@@@@@@@@@@@@@@@@@@@@@\r\n"
"                  @@@@@@@@@@@@@@@@@@@@@@@@@@@@@@@%\r\n"
"               @@@@@@@@@@@@@@@@@@@@@@@@@@@@@@@\r\n"
"                   (@@@@@@@@@@@@@@@@@@@@@\r\n\r\n  OSSAT Dev board OBC Test Program KS-SOF-01541-01\r\n  KISPE Space Systems Ltd.\r\n  list of commands:\r\nA: SRAM Chip Select Test\r\nB: SRAM Write Test\r\nC: SRAM Read Test\r\nH: UART4 test \r\nI: UART2 test\r\nJ: GPIO test\r\nK: Analogue test\r\n";
/**
  * @brief  The application entry point.
  * @retval int
  */
int main(void)
{
  /* USER CODE BEGIN 1 */
	char pData[1];
	pData[0] = '\0';
	RCC_PeriphCLKInitTypeDef PeriphClkInitStruct = {0};
  /* USER CODE END 1 */

  /* MCU Configuration--------------------------------------------------------*/

  /* Reset of all peripherals, Initializes the Flash interface and the Systick. */
  HAL_Init();

  /* Configure the system clock */
  SystemClock_Config();

  /* Initialize all configured peripherals */
  MX_GPIO_Init();

    PeriphClkInitStruct.PeriphClockSelection = RCC_PERIPHCLK_FDCAN;
    PeriphClkInitStruct.FdcanClockSelection = RCC_FDCANCLKSOURCE_PLL;
    if (HAL_RCCEx_PeriphCLKConfig(&PeriphClkInitStruct) != HAL_OK)
    {
      Error_Handler();
    }
    /* Peripheral clock enable */
    HAL_RCC_FDCAN_CLK_ENABLED++;
    if(HAL_RCC_FDCAN_CLK_ENABLED==1){
      __HAL_RCC_FDCAN_CLK_ENABLE();
    }

    PeriphClkInitStruct.PeriphClockSelection = RCC_PERIPHCLK_FDCAN;
    PeriphClkInitStruct.FdcanClockSelection = RCC_FDCANCLKSOURCE_PLL;
    if (HAL_RCCEx_PeriphCLKConfig(&PeriphClkInitStruct) != HAL_OK)
    {
      Error_Handler();
    }

    /* Peripheral clock enable */
    HAL_RCC_FDCAN_CLK_ENABLED++;
    if(HAL_RCC_FDCAN_CLK_ENABLED==1){
      __HAL_RCC_FDCAN_CLK_ENABLE();
    }

  //MX_ADC1_Init();
  //MX_ADC3_Init();
  //MX_FDCAN1_Init();
  //MX_FDCAN2_Init();
  MX_FMC_Init();
  //MX_I2C1_Init();
  //MX_I2C2_Init();
  //MX_SPI1_Init();
  MX_UART4_Init();
  MX_USART2_UART_Init();
  MX_RTC_Init();
  MX_USART3_UART_Init();
  //MX_I2C4_Init();
  GPIO_PinState pinButton1State;
  GPIO_PinState pinButton2State;

  // Initialise the CAN busses
  STM32CAN_Initialise(CAN_PERIPHERAL_FDCAN1, STM32CAN_FDCAN1_MESSAGE_RAM_ADDRESS, CAN_BAUD_1MBPS, 0, 1, 1, 1);
  STM32CAN_Initialise(CAN_PERIPHERAL_FDCAN2, STM32CAN_FDCAN2_MESSAGE_RAM_ADDRESS, CAN_BAUD_1MBPS, 0, 1, 1, 1);
  STM32CAN_RegisterCallbacks(CAN_PERIPHERAL_FDCAN1, CAN1_ISR, 0);
  STM32CAN_RegisterCallbacks(CAN_PERIPHERAL_FDCAN2, CAN2_ISR, 0);
  STM32CAN_Connect(CAN_PERIPHERAL_FDCAN1);
  STM32CAN_Connect(CAN_PERIPHERAL_FDCAN2);

  //HAL_NVIC_EnableIRQ(FDCAN1_IT0_IRQn);
  //HAL_NVIC_EnableIRQ(FDCAN2_IT0_IRQn);
  //HAL_NVIC_EnableIRQ(FDCAN1_IT1_IRQn);
  //HAL_NVIC_EnableIRQ(FDCAN2_IT1_IRQn);

  tsSTM32CAN_Frame tsCANFrame;
  tsCANFrame.iDataLength = 2;
  tsCANFrame.iIdentifier = 0x55;
  tsCANFrame.aData[0] = 0x55;
  tsCANFrame.aData[1] = 0x55;

  STM32CAN_Transmit(CAN_PERIPHERAL_FDCAN1, &tsCANFrame,1);
  STM32CAN_Transmit(CAN_PERIPHERAL_FDCAN2, &tsCANFrame,1);
  /* USER CODE BEGIN 2 */
  // for this board, PC10: USART3_TX, PC11: USART3_RX

  // print the splash screen and wait for something to happen
  HAL_UART_Transmit(&huart3, pcSplashScreen, strlen(pcSplashScreen), 500);
  /* USER CODE END 2 */

  // Toggle between LED1 and LED2
  // LED 1 is PG6
  // LED 2 is PG7
  // LED 3 is PG8
  // USER_BUTTON_1 is PC6
  // USER_BUTTON_2 is PC4
  // Set LED1
  HAL_GPIO_WritePin(GPIOG, 0x0040, GPIO_PIN_SET);

  /* Infinite loop */
  /* USER CODE BEGIN WHILE */
  while (1)
  {
	pData[0] = '\0';
    // Read the UART3 for a character... wait 1/4 second
	HAL_UART_Receive(&huart3, pData, 1, 250);

	// Toggle LED 1 & 2
	HAL_GPIO_TogglePin(GPIOG, 0x00C0);
	// Read the buttons PC4 & 6

	pinButton2State = HAL_GPIO_ReadPin(GPIOC, 0x0010);
	pinButton1State = HAL_GPIO_ReadPin(GPIOC, 0x0040);

	// set LED 3 if someone is pressing button 2
	if (pinButton2State == GPIO_PIN_RESET)
	{
		// set LED 3
		HAL_GPIO_WritePin(GPIOG, 0x0100, GPIO_PIN_SET);
	}
	// reset LED 3 if someone is pressing button 1
	if (pinButton1State == GPIO_PIN_RESET)
	{
		// reset LED 3
		HAL_GPIO_WritePin(GPIOG, 0x0100, GPIO_PIN_RESET);
	}

	switch (pData[0])
	{
	case 'A':
		HAL_UART_Transmit(&huart3, "Starting Memory CS Decoder Test\r\n", 33, 1000);
		MRAM_CSTest();
		break;
	case 'B':
		HAL_UART_Transmit(&huart3, "Starting MRAM Write Test\r\n", 26, 1000);
		MRAM_WriteTest();
		break;
	case 'C':
		HAL_UART_Transmit(&huart3, "Starting MRAM Read Test\r\n", 25, 1000);
		MRAM_ReadTest();
		break;
	case 'H':
		HAL_UART_Transmit(&huart3, "Starting UART4 Testing, waiting for UART character\r\n", 52, 1000);
		UART_Test(&huart4);
		break;
	case 'I':
		HAL_UART_Transmit(&huart3, "Starting UART2 Testing, waiting for UART character\r\n", 52, 1000);
		UART_Test(&huart2);
		break;
	case 'J':
		HAL_UART_Transmit(&huart3, "Starting GPIO test, pulsing successive outputs\r\n", 49, 1000);
		GPIO_Test();
		break;
	case 'K':
		HAL_UART_Transmit(&huart3, "Starting ADC test, pulsing successive ADC inputs\r\n", 50, 1000);
		ANALOGUE_Test();
		break;
	case 'L':
		HAL_UART_Transmit(&huart3, "Starting PPS test\r\n", 19, 1000);
		PPS_Test();
		break;
	case 'M':
		HAL_UART_Transmit(&huart3, "Starting LVDS, Data Ready to MOSI test. Looping back for 10s\r\n", 62, 1000);
		LVDS_DR_To_MOSI_Test();
		break;
	case 'N':
		HAL_UART_Transmit(&huart3, "Starting LVDS, Data Ready to NSS test. Looping back for 10s\r\n", 61, 1000);
		LVDS_DR_To_NSS_Test();
		break;
	case 'O':
		HAL_UART_Transmit(&huart3, "Starting LVDS, Data Ready to SCK test. Looping back for 10s\r\n", 61, 1000);
		LVDS_DR_To_SCK_Test();
		break;
	case 'P':
		HAL_UART_Transmit(&huart3, "Starting LVDS, EXTI9 to MOSI test. Looping back for 10s\r\n", 56, 1000);
		LVDS_EXTI9_To_MOSI_Test();
		break;
	case 'Q':
		HAL_UART_Transmit(&huart3, "Starting LVDS, EXTI9 to NSS test. Looping back for 10s\r\n", 57, 1000);
		LVDS_EXTI9_To_NSS_Test();
		break;
	case 'R':
		HAL_UART_Transmit(&huart3, "Starting LVDS, EXTI9 to SCK test. Looping back for 10s\r\n", 57, 1000);
		LVDS_EXTI9_To_SCK_Test();
		break;
	default:
		break;
	}

    /* USER CODE END WHILE */

    /* USER CODE BEGIN 3 */
  }
  /* USER CODE END 3 */
}

unsigned int CAN1_Test_Running = 0;
unsigned int CAN2_Test_Running = 0;


static void CAN1_Test(void)
{
	CAN1_Test_Running = 1;
	HAL_Delay(10000);
	CAN1_Test_Running = 0;

	HAL_UART_Transmit(&huart3, pcSplashScreen, strlen(pcSplashScreen), 1000);
}

static void CAN2_Test(void)
{
	CAN2_Test_Running = 1;
	HAL_Delay(10000);
	CAN2_Test_Running = 0;

	HAL_UART_Transmit(&huart3, pcSplashScreen, strlen(pcSplashScreen), 1000);
}

void CAN1_ISR(void)
{
	unsigned int *pBufferStartAddress;
	unsigned int *piIndexOfFirstFrame;
	unsigned int *piNumFramesToRead;
	unsigned int *piMaxFramesInFIFO;
	unsigned int i = 0;
	STM32CAN_Receive(CAN_PERIPHERAL_FDCAN1, pBufferStartAddress, piIndexOfFirstFrame, piNumFramesToRead, piMaxFramesInFIFO);

	// if the test is running
	if (CAN1_Test_Running == 1)
	{
		tsSTM32CAN_Frame tsCANFrame;
		tsCANFrame.iIdentifier = ((tsSTM32CAN_RXFifoElement*)pBufferStartAddress)->iID;
		tsCANFrame.iDataLength = ((tsSTM32CAN_RXFifoElement*)pBufferStartAddress)->iDLC;
		for (i = 0 ; i < tsCANFrame.iDataLength ; i++ )
		{
			tsCANFrame.aData[i] = ((tsSTM32CAN_RXFifoElement*)pBufferStartAddress)->aDataBytes[i];
		}

		STM32CAN_Transmit(CAN_PERIPHERAL_FDCAN1, &tsCANFrame, 1);
	}
	else
	{
		STM32CAN_Flush(CAN_PERIPHERAL_FDCAN1);
	}
}

void CAN2_ISR(void)
{
	unsigned int *pBufferStartAddress;
	unsigned int *piIndexOfFirstFrame;
	unsigned int *piNumFramesToRead;
	unsigned int *piMaxFramesInFIFO;
	unsigned int i = 0;
	STM32CAN_Receive(CAN_PERIPHERAL_FDCAN2, pBufferStartAddress, piIndexOfFirstFrame, piNumFramesToRead, piMaxFramesInFIFO);

	// if the test is running
	if (CAN2_Test_Running == 1)
	{
		tsSTM32CAN_Frame tsCANFrame;
		tsCANFrame.iIdentifier = ((tsSTM32CAN_RXFifoElement*)pBufferStartAddress)->iID;
		tsCANFrame.iDataLength = ((tsSTM32CAN_RXFifoElement*)pBufferStartAddress)->iDLC;
		for (i = 0 ; i < tsCANFrame.iDataLength ; i++ )
		{
			tsCANFrame.aData[i] = ((tsSTM32CAN_RXFifoElement*)pBufferStartAddress)->aDataBytes[i];
		}

		STM32CAN_Transmit(CAN_PERIPHERAL_FDCAN2, &tsCANFrame, 1);
	}
	else
	{
		STM32CAN_Flush(CAN_PERIPHERAL_FDCAN2);
	}
}

// Perform a test of the decoders that are used to assert the Chip Select signals.
static void MRAM_CSTest(void)
{
	HAL_UART_Transmit(&huart3, "Intialising the FMC to connect the MRAM\r\n", 41, 1000);

	int i = 0;
	int j = 0;
	unsigned short *pMRAMLocation;
	unsigned short actualValue;
	char cCounterChar;

	// FMC bank 1 registers
	int *piFMC_BCR1 = 0x52004000;
	int *piFMC_BTR1 = 0x52004004;

	// pointer to the MRAM
	unsigned short *piMRAM = MRAM_START_ADDRESS;

	unsigned short Value = 0U;
	unsigned int iLoopCounter = 0UL;

    // set the BTR register to 00000000000000000000000100000010 (binary) 0x00000102 (hex)
	// See the above commentry for justification
	*piFMC_BTR1 = 0x00000202UL;
	//*piFMC_BTR1 = 0x0000FF08UL;
	// Set the BCR register to 1000 0000 0010 0000 0001 0000 1001 0001 (binary) 0x80201091 (hex)
	// See the above commentry for justification
	*piFMC_BCR1 = 0x81201091UL;

	// run through all 10 chip selects
	for (i=0 ; i < 10 ; i++)
	{
		// address the next chip
		pMRAMLocation = MRAM_START_ADDRESS + (i* MRAM_SINGLE_CHIP_SIZE);
		HAL_UART_Transmit(&huart3, "Writing to MRAM at chip select #", 32, 1000);
		cCounterChar = i + 48;
		HAL_UART_Transmit(&huart3, &cCounterChar, 1, 1000);
		HAL_UART_Transmit(&huart3, "\r\n", 2, 1000);

		// fill the first 10 locations with content
		for(j=0 ; j < 10 ; j++)
		{
			*pMRAMLocation = (unsigned short)j;
			pMRAMLocation++;
		}

		// reset the pointer to the start address of this chip.
		pMRAMLocation = MRAM_START_ADDRESS + (i* MRAM_SINGLE_CHIP_SIZE);
		// check that the chip is storing the first 10 locations
		for (j=0 ; j < 10 ; j++)
		{
			actualValue = *pMRAMLocation;
			pMRAMLocation++;
			if (actualValue != j)
			{
				HAL_UART_Transmit(&huart3, "Error reading MRAM at chip select #", 35, 1000);
				cCounterChar = i + 48;
				HAL_UART_Transmit(&huart3, &cCounterChar, 1, 1000);
				HAL_UART_Transmit(&huart3, "\r\n", 2, 1000);
				j = 20;
			}
		}
		// if the test was successful.
		if (j == 10)
		{
			HAL_UART_Transmit(&huart3, "Successfully wrote and read data at chip select #", 49, 1000);
			cCounterChar = i + 48;
			HAL_UART_Transmit(&huart3, &cCounterChar, 1, 1000);
			HAL_UART_Transmit(&huart3, "\r\n", 2, 1000);
		}

	}
	HAL_UART_Transmit(&huart3, pcSplashScreen, strlen(pcSplashScreen), 1000);

}

static void UART_Test(UART_HandleTypeDef *huart)
{
	HAL_StatusTypeDef status;
	char pData[1];

	// perform dummy read to flush UART
	HAL_UART_Receive(huart, pData, 1, 0);

	status = HAL_UART_Receive(huart, pData, 1, 10000);
	if (status == HAL_TIMEOUT)
	{
		HAL_UART_Transmit(&huart3, "Nothing received\r\n", 18, 1000);
	}
	else
	{
		HAL_UART_Transmit(&huart3, "Received ", 10, 1000);
		HAL_UART_Transmit(&huart3, pData, 1, 1000);

		HAL_UART_Transmit(&huart3, " echoing on UART\r\n", 18, 1000);
		HAL_UART_Transmit(huart, pData, 1, 1000);
	}

	HAL_UART_Transmit(&huart3, pcSplashScreen, strlen(pcSplashScreen), 1000);
}

static void LVDS_DR_To_MOSI_Test(void)
{
	LoopBackIoTest(GPIOG, 0x8000, GPIOD, 0x0080);
}
static void LVDS_DR_To_NSS_Test(void)
{
	LoopBackIoTest(GPIOG, 0x8000, GPIOG, 0x0400);
}
static void LVDS_DR_To_SCK_Test(void)
{
	LoopBackIoTest(GPIOG, 0x8000, GPIOG, 0x0800);
}
static void LVDS_EXTI9_To_MOSI_Test(void)
{
	LoopBackIoTest(GPIOG, 0x0200, GPIOD, 0x0080);
}
static void LVDS_EXTI9_To_NSS_Test(void)
{
	LoopBackIoTest(GPIOG, 0x0200, GPIOG, 0x0400);
}
static void LVDS_EXTI9_To_SCK_Test(void)
{
	LoopBackIoTest(GPIOG, 0x0200, GPIOG, 0x0800);
}


static void LoopBackIoTest(GPIO_TypeDef *InputGPIOx, uint16_t InputGPIO_Pin, GPIO_TypeDef *OutputGPIOx, uint16_t OutputGPIO_Pin)
{
	unsigned int tEndTime, tStartTime, tCurrentTime;
	tStartTime = HAL_GetTick();
	tEndTime = tStartTime + 10000; // end time is 10 seconds in the future
	tCurrentTime = tStartTime;
	GPIO_PinState PinState;

	// while 10 seconds are not yet up
	while (tCurrentTime < tEndTime)
	{
		// sample the input IO
		PinState = HAL_GPIO_ReadPin(InputGPIOx , InputGPIO_Pin);
		HAL_GPIO_WritePin(OutputGPIOx, OutputGPIO_Pin, PinState);

		// set the output given the input
		tCurrentTime = HAL_GetTick();
	}

	HAL_UART_Transmit(&huart3, pcSplashScreen, strlen(pcSplashScreen), 1000);
}


// a struct to hold the pin mappings.
typedef struct tePinMapping
{
	GPIO_TypeDef *GPIOx;
	uint16_t     GPIO_Pin;
} tePinMapping;

static void GPIO_Test(void)
{
	tePinMapping teGPIOPinMapping[31] =
	{
		{GPIOB, 0x0020},
		{GPIOG, 0x4000},
		{GPIOF, 0x0400},
		{GPIOF, 0x0100},
		{GPIOF, 0x0080},
		{GPIOF, 0x0040},
		{GPIOA, 0x0100},
		{GPIOC, 0x0200},
		{GPIOB, 0x4000},
		{GPIOB, 0x8000},
		{GPIOG, 0x1000},
		{GPIOD, 0x0040},
		{GPIOD, 0x0008},
		{GPIOD, 0x0004},
		{GPIOC, 0x1000},
		{GPIOA, 0x0400},
		{GPIOA, 0x0200},
		{GPIOC, 0x0100},
		{GPIOB, 0x0004},
		{GPIOA, 0x0020},
		{GPIOG, 0x0200},
		{GPIOD, 0x0080},
		{GPIOG, 0x0800},
		{GPIOG, 0x0400},
		{GPIOB, 0x0200},
		{GPIOB, 0x0100},
		{GPIOG, 0x8000},
		{GPIOB, 0x0800},
		{GPIOB, 0x0400},
		{GPIOB, 0x0080},
		{GPIOB, 0x0040}
	};
	int Counter = 0UL;

	HAL_UART_Transmit(&huart3, "GPIO Tests, cycling GPIO lines\r\n", 32, 1000);

	for (Counter = 0UL ; Counter < 31UL ; Counter++)
	{
		char cCounterChar = (Counter%10) + 48; // convert number to ASCII
		// set one output high
		HAL_UART_Transmit(&huart3, "Setting GPIO output ", 20, 1000);
		if ((Counter > 9) && (Counter <= 19))
		{
			HAL_UART_Transmit(&huart3, "1", 1, 1000);
		}
	    if ((Counter > 19) && (Counter <= 29))
		{
	    	HAL_UART_Transmit(&huart3, "2", 1, 1000);
		}
	    if (Counter == 30)
	    {
	    	HAL_UART_Transmit(&huart3, "3", 1, 1000);
	    }
		HAL_UART_Transmit(&huart3, &cCounterChar, 1, 1000);
		HAL_UART_Transmit(&huart3, " high\r\n", 7, 1000);

		HAL_GPIO_WritePin(teGPIOPinMapping[Counter].GPIOx, teGPIOPinMapping[Counter].GPIO_Pin, GPIO_PIN_SET);

		// wait for 0.025 seconds
		HAL_Delay(25);

		// set one output low
		HAL_UART_Transmit(&huart3, "Setting GPIO output ", 20, 1000);
		if ((Counter > 9) && (Counter <= 19))
		{
			HAL_UART_Transmit(&huart3, "1", 1, 1000);
		}
		if ((Counter > 19) && (Counter <= 29))
		{
		   	HAL_UART_Transmit(&huart3, "2", 1, 1000);
		}
		if (Counter == 30)
		{
		   	HAL_UART_Transmit(&huart3, "3", 1, 1000);
		}
		HAL_UART_Transmit(&huart3, &cCounterChar, 1, 1000);
		HAL_UART_Transmit(&huart3, " low\r\n", 6, 1000);

		HAL_GPIO_WritePin(teGPIOPinMapping[Counter].GPIOx, teGPIOPinMapping[Counter].GPIO_Pin, GPIO_PIN_RESET);

		// wait for 0.025 seconds
		HAL_Delay(25);
	}

	HAL_UART_Transmit(&huart3, pcSplashScreen, strlen(pcSplashScreen), 1000);
}

static void ANALOGUE_Test(void)
{
	int Counter;
	tePinMapping teAnalogueInputPinMapping[8] =
		{
			{GPIOF, 0x0800},
			{GPIOA, 0x0040},
			{GPIOB, 0x0002},
			{GPIOC, 0x0020},
			{GPIOC, 0x0004},
			{GPIOC, 0x0008},
			{GPIOC, 0x0001},
			{GPIOC, 0x0002}
		};

	HAL_UART_Transmit(&huart3, "\r\nAnalogue Input Tests, cycling through Inputs\r\n", 48, 1000);

	for (Counter = 0UL ; Counter < 8UL ; Counter++)
	{
		char cCounterChar = Counter + 48; // convert number to ASCII
		// set one output high
		HAL_UART_Transmit(&huart3, "Setting analogue input ", 23, 1000);
		HAL_UART_Transmit(&huart3, &cCounterChar, 1, 1000);
		HAL_UART_Transmit(&huart3, " high\r\n", 7, 1000);

		HAL_GPIO_WritePin(teAnalogueInputPinMapping[Counter].GPIOx, teAnalogueInputPinMapping[Counter].GPIO_Pin, GPIO_PIN_SET);
		// wait for 0.25 seconds
		HAL_Delay(250);
		// set one output low
		HAL_UART_Transmit(&huart3, "Setting analogue input ", 23, 1000);
		HAL_UART_Transmit(&huart3, &cCounterChar, 1, 1000);
		HAL_UART_Transmit(&huart3, " low\r\n", 6, 1000);
		HAL_GPIO_WritePin(teAnalogueInputPinMapping[Counter].GPIOx, teAnalogueInputPinMapping[Counter].GPIO_Pin, GPIO_PIN_RESET);
		// wait for 0.25 seconds
		HAL_Delay(250);
	}
	HAL_UART_Transmit(&huart3, pcSplashScreen, strlen(pcSplashScreen), 1000);

}


void I2C1_Test(void)
{
	HAL_UART_Transmit(&huart3, "I2C1 test, setting clock and data low\r\n", 39, 1000);

	// deassert data
	HAL_GPIO_WritePin(GPIOB, 0x0080, GPIO_PIN_RESET);

	// deassert clock
	HAL_GPIO_WritePin(GPIOB, 0x0040, GPIO_PIN_RESET);

	HAL_Delay(250);
	HAL_UART_Transmit(&huart3, "I2C1 test, setting clock and data high\r\n", 40, 1000);

	// assert clock
	HAL_GPIO_WritePin(GPIOB, 0x0040, GPIO_PIN_SET);
	// assert data
	HAL_GPIO_WritePin(GPIOB, 0x0080, GPIO_PIN_SET);

	HAL_Delay(250);
	HAL_UART_Transmit(&huart3, "I2C1 test, setting clock and data low\r\n", 39, 1000);

	// deassert data
	HAL_GPIO_WritePin(GPIOB, 0x0080, GPIO_PIN_RESET);

	// deassert clock
	HAL_GPIO_WritePin(GPIOB, 0x0040, GPIO_PIN_RESET);


	HAL_UART_Transmit(&huart3, pcSplashScreen, strlen(pcSplashScreen), 1000);
}

void I2C2_Test(void)
{
	HAL_UART_Transmit(&huart3, "I2C2 test, setting clock and data low\r\n", 39, 1000);

	// deassert data
	HAL_GPIO_WritePin(GPIOB, 0x0800, GPIO_PIN_RESET);

	// deassert clock
	HAL_GPIO_WritePin(GPIOB, 0x0400, GPIO_PIN_RESET);

	HAL_Delay(250);
	HAL_UART_Transmit(&huart3, "I2C2 test, setting clock and data high\r\n", 40, 1000);

	// assert clock
	HAL_GPIO_WritePin(GPIOB, 0x0400, GPIO_PIN_SET);
	// assert data
	HAL_GPIO_WritePin(GPIOB, 0x0800, GPIO_PIN_SET);

	HAL_Delay(250);
	HAL_UART_Transmit(&huart3, "I2C2 test, setting clock and data low\r\n", 39, 1000);

	// deassert data
	HAL_GPIO_WritePin(GPIOB, 0x0800, GPIO_PIN_RESET);

	// deassert clock
	HAL_GPIO_WritePin(GPIOB, 0x0400, GPIO_PIN_RESET);

	HAL_UART_Transmit(&huart3, pcSplashScreen, strlen(pcSplashScreen), 1000);
}

void I2C4_Test(void)
{
	HAL_UART_Transmit(&huart3, "I2C4 test, setting clock and data low\r\n", 39, 1000);

	// deassert data
	HAL_GPIO_WritePin(GPIOB, 0x0200, GPIO_PIN_RESET);

	// deassert clock
	HAL_GPIO_WritePin(GPIOB, 0x0100, GPIO_PIN_RESET);

	HAL_Delay(250);
	HAL_UART_Transmit(&huart3, "I2C4 test, setting clock and data high\r\n", 40, 1000);

	// assert clock
	HAL_GPIO_WritePin(GPIOB, 0x0100, GPIO_PIN_SET);
	// assert data
	HAL_GPIO_WritePin(GPIOB, 0x0200, GPIO_PIN_SET);

	HAL_Delay(250);
	HAL_UART_Transmit(&huart3, "I2C4 test, setting clock and data low\r\n", 39, 1000);

	// deassert data
	HAL_GPIO_WritePin(GPIOB, 0x0200, GPIO_PIN_RESET);

	// deassert clock
	HAL_GPIO_WritePin(GPIOB, 0x0100, GPIO_PIN_RESET);

	HAL_UART_Transmit(&huart3, pcSplashScreen, strlen(pcSplashScreen), 1000);
}
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

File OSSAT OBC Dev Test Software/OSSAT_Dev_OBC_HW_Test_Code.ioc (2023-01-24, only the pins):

Mcu.UserName=STM32H753ZITx
PA0.Signal=UART4_TX
PA1.Signal=UART4_RX
PA10.Signal=GPIO_Input
PA11.Signal=FDCAN1_RX
PA12.Signal=FDCAN1_TX
PA2.Signal=USART2_TX
PA3.Signal=USART2_RX
PA5.Signal=GPIO_Input
PA6.Signal=ADCx_INP3
PA8.Signal=GPIO_Output
PA9.Signal=GPIO_Input
PB1.Signal=ADCx_INP5
PB10.Signal=I2C2_SCL
PB11.Signal=I2C2_SDA
PB12.Signal=FDCAN2_RX
PB13.Signal=FDCAN2_TX
PB14.Signal=GPIO_Output
PB15.Signal=GPIO_Output
PB2.Signal=GPIO_Input
PB5.Signal=GPIO_Output
PB6.Signal=I2C1_SCL
PB7.Signal=I2C1_SDA
PB8.Signal=I2C4_SCL
PB9.Signal=I2C4_SDA
PC0.Signal=ADCx_INP10
PC1.Signal=ADCx_INP11
PC10.Signal=USART3_TX
PC11.Signal=USART3_RX
PC12.Signal=GPIO_Input
PC13.Signal=RTC_OUT_CALIB
PC2_C.Signal=ADC3_INP0
PC3_C.Signal=ADC3_INP1
PC4.Signal=GPIO_Output
PC5.Signal=ADCx_INP8
PC6.Signal=GPIO_Input
PC7.Signal=FMC_NE1
PC8.Signal=GPIO_Input
PC9.Signal=GPIO_Output
PD0.Signal=FMC_D2_DA2
PD1.Signal=FMC_D3_DA3
PD10.Signal=FMC_D15_DA15
PD11.Signal=FMC_A16_CLE
PD12.Signal=FMC_A17_ALE
PD13.Signal=FMC_A18
PD14.Signal=FMC_D0_DA0
PD15.Signal=FMC_D1_DA1
PD2.Signal=GPIO_Input
PD3.Signal=GPIO_Input
PD4.Signal=FMC_NOE
PD5.Signal=FMC_NWE
PD6.Signal=GPIO_Input
PD7.Signal=SPI1_MOSI
PD8.Signal=FMC_D13_DA13
PD9.Signal=FMC_D14_DA14
PE0.Signal=FMC_NBL0
PE1.Signal=FMC_NBL1
PE10.Signal=FMC_D7_DA7
PE11.Signal=FMC_D8_DA8
PE12.Signal=FMC_D9_DA9
PE13.Signal=FMC_D10_DA10
PE14.Signal=FMC_D11_DA11
PE15.Signal=FMC_D12_DA12
PE2.Signal=FMC_A23
PE3.Signal=FMC_A19
PE4.Signal=FMC_A20
PE5.Signal=FMC_A21
PE6.Signal=FMC_A22
PE7.Signal=FMC_D4_DA4
PE8.Signal=FMC_D5_DA5
PE9.Signal=FMC_D6_DA6
PF0.Signal=FMC_A0
PF1.Signal=FMC_A1
PF10.Signal=GPIO_Output
PF11.Signal=ADC1_INP2
PF12.Signal=FMC_A6
PF13.Signal=FMC_A7
PF14.Signal=FMC_A8
PF15.Signal=FMC_A9
PF2.Signal=FMC_A2
PF3.Signal=FMC_A3
PF4.Signal=FMC_A4
PF5.Signal=FMC_A5
PF6.Signal=GPIO_Output
PF7.Signal=GPIO_Output
PF8.Signal=GPIO_Output
PF9.Signal=GPIO_Input
PG0.Signal=FMC_A10
PG1.Signal=FMC_A11
PG10.Signal=SPI1_NSS
PG11.Signal=SPI1_SCK
PG12.Signal=GPIO_Input
PG13.Signal=FMC_A24
PG14.Signal=GPIO_Output
PG15.Signal=GPXTI15
PG2.Signal=FMC_A12
PG3.Signal=FMC_A13
PG4.Signal=FMC_A14_BA0
PG5.Signal=FMC_A15_BA1
PG6.Signal=GPIO_Output
PG7.Signal=GPIO_Output
PG8.Signal=GPIO_Output
PG9.Signal=GPXTI9

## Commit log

2023-01-16 added STM32 screenshot
2023-01-16 corrected reference to STM32 screenshot
2023-01-16 adding powershell screenshot.
2023-01-16 Adding schematics
2023-01-31 Add files via upload
    Added Gerber manufacturing files in a zip file
2023-01-31 Add files via upload
    Added fusion 360 CAD source files, comprising Schematic, PCB and Library file. all in an old Eagle format, to ensure maximum conpatibility.
    [KS-SCH-01466-01 OSSAT OBC Dev Board Schematic.sch, KS-SCH-01467 OSSAT OBC Dev Board PCB.brd]
2023-02-01 Add files via upload
    Added BOM and PCB Layer stackup document
    [KS-SCH-01466-01 OSSAT OBC Dev Brd BOM with Mfr Data.xlsx]
2023-02-01 Add files via upload
    Added PCB assembly build document
2023-02-03 Update README.md
    Added the section: Intro to OBC Development Board
2023-02-10 Add files via upload
    Added test doc for the board
2023-02-15 Add files via upload
    Minor corrections to Schematic, to change MRAM references to SRAM, also removed RXDAT Ready Reference
    [KS-SCH-01466-01 OSSAT OBC Dev Board Schematic.sch]
2023-02-15 Add files via upload
    Minor corrections, including referencing the BOM and software correctly
2023-02-15 Delete KS-SCH-01466 V01 OSSAT OBC Dev Board Schematic.pdf
    File deleted, due to newer version with corrected name added
2023-02-15 Update README.md
    Updated the link to the PDF schematic, because name slightly changed

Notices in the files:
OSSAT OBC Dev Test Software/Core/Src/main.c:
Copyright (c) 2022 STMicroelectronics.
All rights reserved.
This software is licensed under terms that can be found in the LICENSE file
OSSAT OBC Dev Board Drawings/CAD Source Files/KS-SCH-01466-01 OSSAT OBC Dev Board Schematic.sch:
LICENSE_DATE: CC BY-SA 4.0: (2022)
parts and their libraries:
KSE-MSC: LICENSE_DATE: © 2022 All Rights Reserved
